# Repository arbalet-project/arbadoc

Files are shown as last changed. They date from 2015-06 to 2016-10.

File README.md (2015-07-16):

# Arbalet project
## Hackable LED table for geeks and pleasure
Arbalet is an *ARduino-BAsed LED Table*, a flat surface filled with several hundreds of coloured square lights designed for _Education_, _Geeks_, and _Pleasure_. With its limited number of pixels, Arbalet brings our old 80 arcad games back into fashion through a modern, classy, and hackable device.

Arbalet is intended to be easily reproducible, highly customizable, and programmable to create new games, light animations and applications. It's not only a LED table, it's an open development platform. Whether you're looking for a modern, stylish and ready-to-use platform for your home, or a hackable and original platform to teach programming and develop exciting projects, Arbalet is made for you!

Wanna get more information and/or start hacking? Please consult the [Arbalet wiki](https://github.com/arbalet-project/arbadoc/wiki), here is a video trailer to whet your appetite:

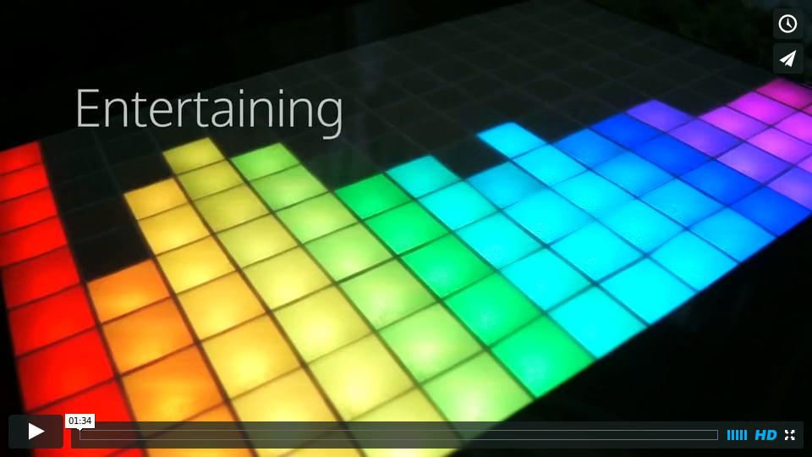
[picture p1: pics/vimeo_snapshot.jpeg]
Arbalet video trailer (https://vimeo.com/arbalet/1)


The project has just started and is looking for beta-testers and passionate makers, to keep in touch: Follow @arbalet_project on Twitter (https://twitter.com/arbalet_project)

## Arbadoc
Arbalet's source code is organized around three repositories: [Arbasdk](https://github.com/arbalet-project/arbasdk) (Python SDK), [Arbapps](https://github.com/arbalet-project/arbapps) (Applications) and Arbadoc.

This repository Arbadoc contains all extra files and pictures related to the documentation. This is probably not very interesting to browse this repository by hand, consult the [Arbalet wiki](https://github.com/arbalet-project/arbadoc/wiki) instead.

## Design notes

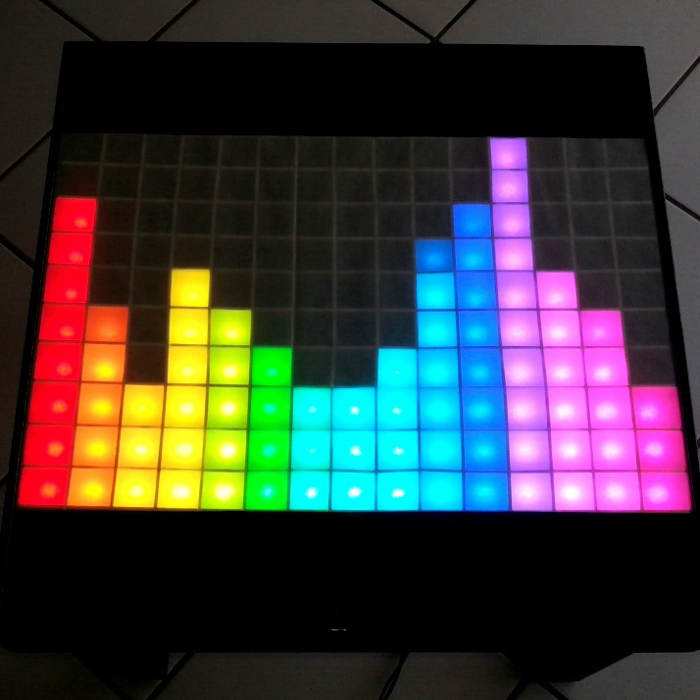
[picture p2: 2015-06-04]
pics/spectrum_analyser.jpg

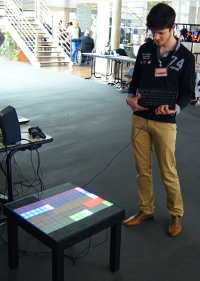
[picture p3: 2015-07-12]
pics/lights_hero_florian_thumbnail.jpg

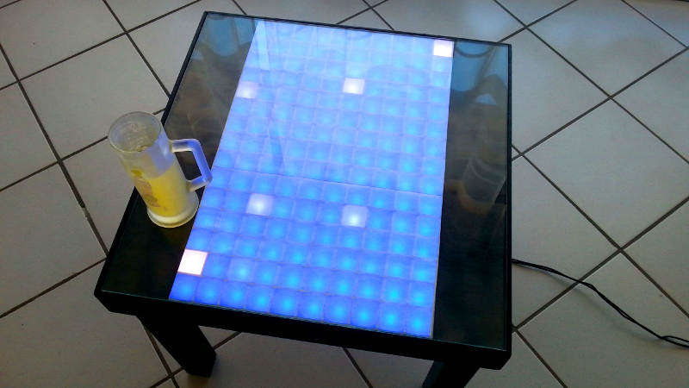
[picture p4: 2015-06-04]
pics/beer_and_flashes.jpg

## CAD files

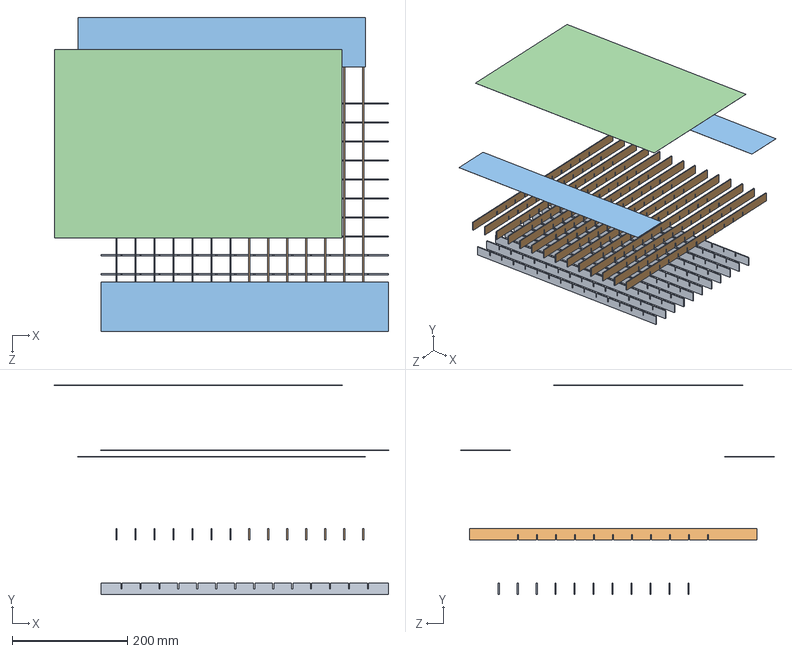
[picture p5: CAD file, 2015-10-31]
assembly_guidelines/lack/cad/Arbalet_GRID_ASM.SLDASM
580.8 x 363.9 x 545.8 mm
Arbalet_GRID_14 x 11
Arbalet_GRID_11 x 14
Arbalet_GRID_COVER x 2
Arbalet_GRID_Diffuser

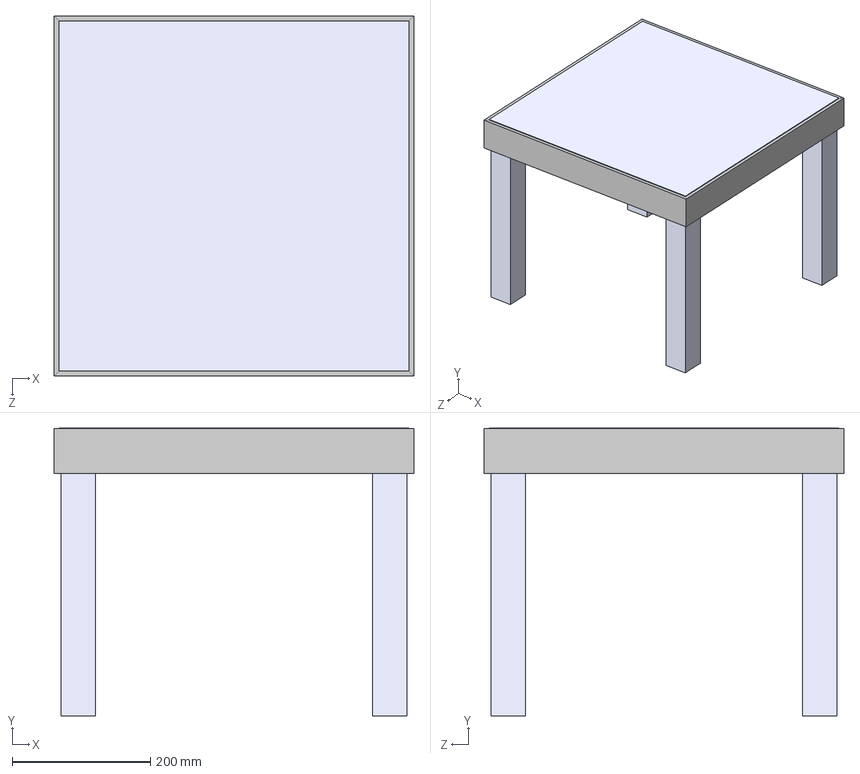
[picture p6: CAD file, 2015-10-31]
assembly_guidelines/lack/cad/Arbalet_ASM.STEP
520.0 x 416.0 x 520.0 mm
Arbalet_UPPER_TRAY_Glass
Arbalet_UPPER_TRAY_Frame x 4
Arbalet_GRID_14 x 11
Arbalet_GRID_11 x 14
Arbalet_GRID_COVER x 2
Arbalet_GRID_Diffuser
Arbalet_ELECTRONIC_STRIP x 10
Arbalet_TABLE_Tray
Arbalet_TABLE_LEG x 4
Arbalet_ELECTRONIC_Tape x 10

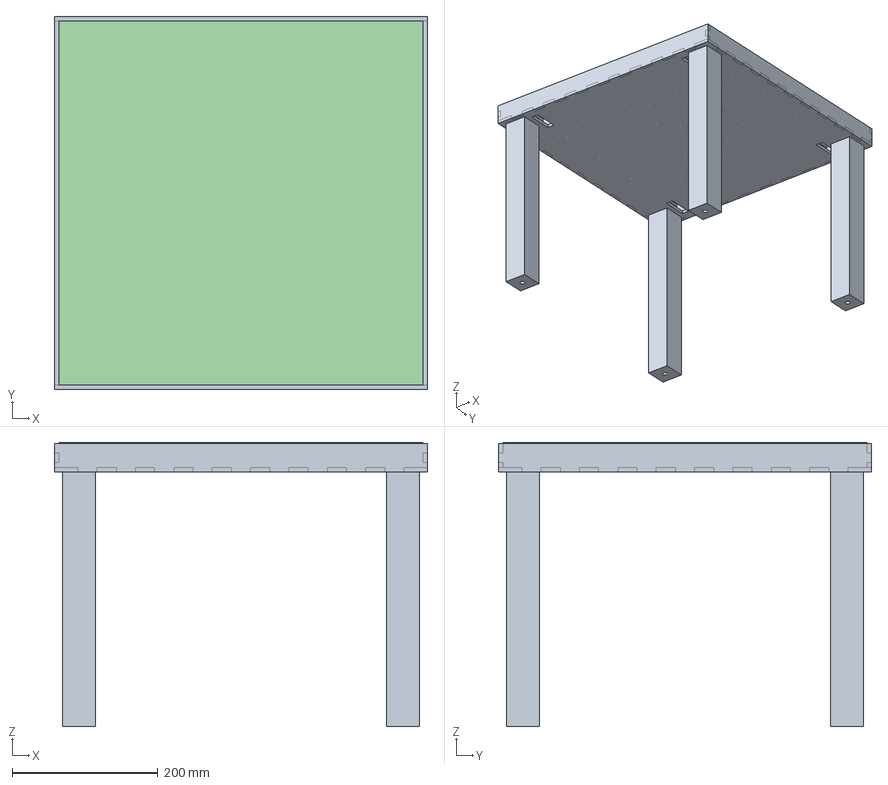
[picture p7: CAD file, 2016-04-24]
assembly_guidelines/lava/cad/covered_assembly.fcstd
512.0 x 512.0 x 390.5 mm
host_box_grid_legs_01
cover_sheet_01
cover_sheet_02
glass_01

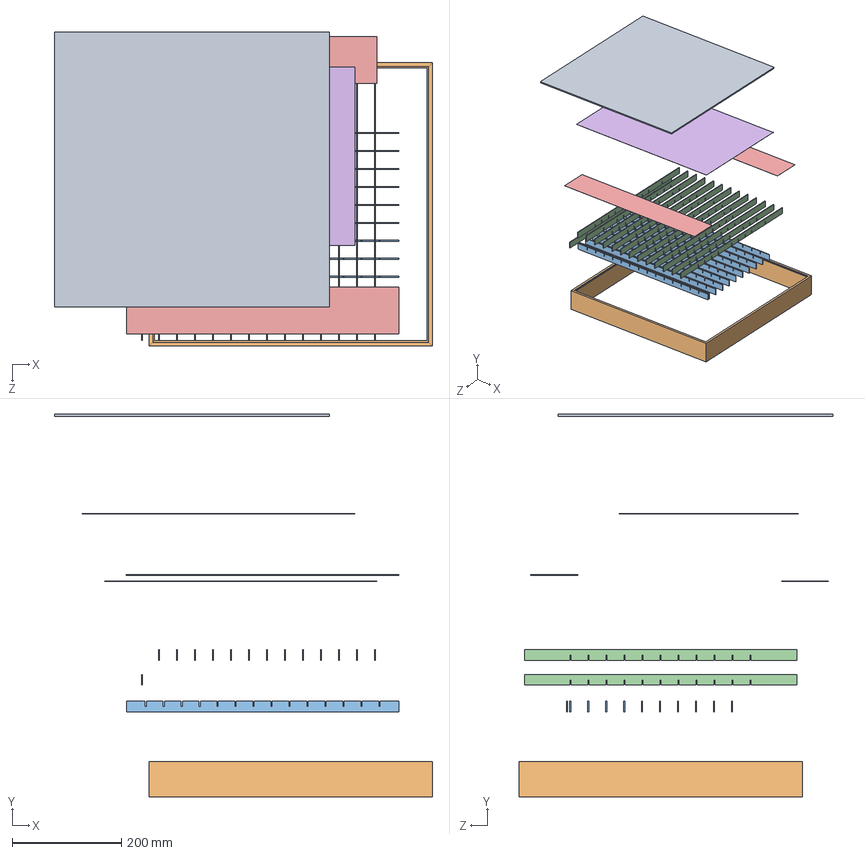
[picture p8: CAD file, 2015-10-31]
assembly_guidelines/lack/cad/Arbalet_UPPER_TRAY_ASM.SLDASM
693.6 x 702.2 x 576.6 mm
Arbalet_UPPER_TRAY_Glass
Arbalet_UPPER_TRAY_Frame x 4
Arbalet_GRID_14 x 11
Arbalet_GRID_11 x 14
Arbalet_GRID_COVER x 2
Arbalet_GRID_Diffuser

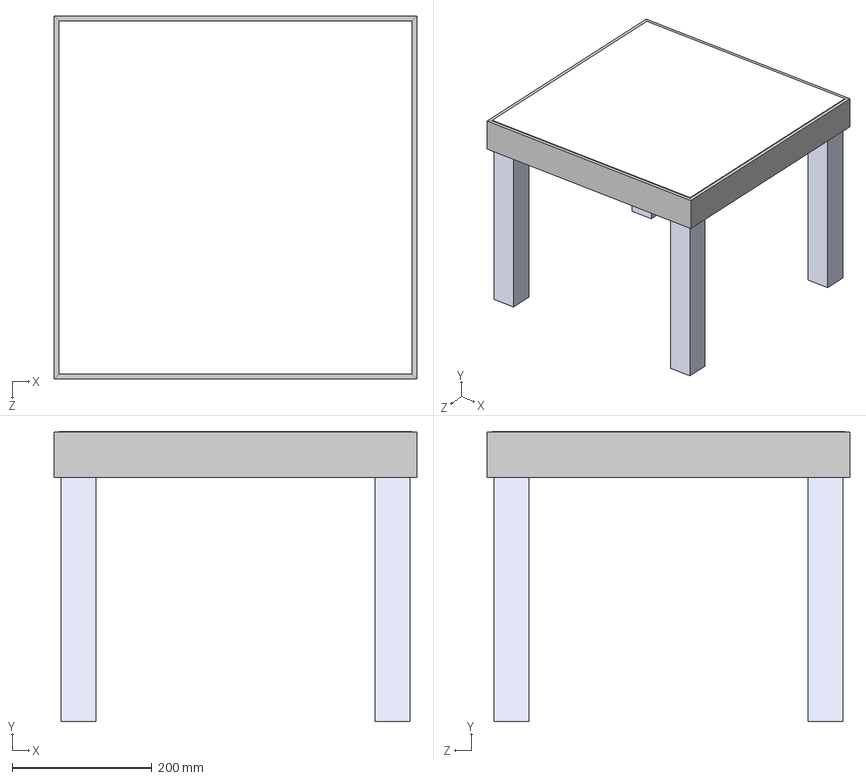
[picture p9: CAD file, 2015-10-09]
assembly_guidelines/lack/cad/Arbalet_ASM_step.STEP
520.0 x 416.0 x 520.0 mm
Arbalet_UPPER_TRAY_Glass
Arbalet_UPPER_TRAY_Frame x 4
Arbalet_GRID_14 x 11
Arbalet_GRID_11 x 14
Arbalet_GRID_COVER x 2
Arbalet_GRID_Diffuser
Arbalet_ELECTRONIC_STRIP x 10
Arbalet_TABLE_Tray
Arbalet_TABLE_LEG x 4

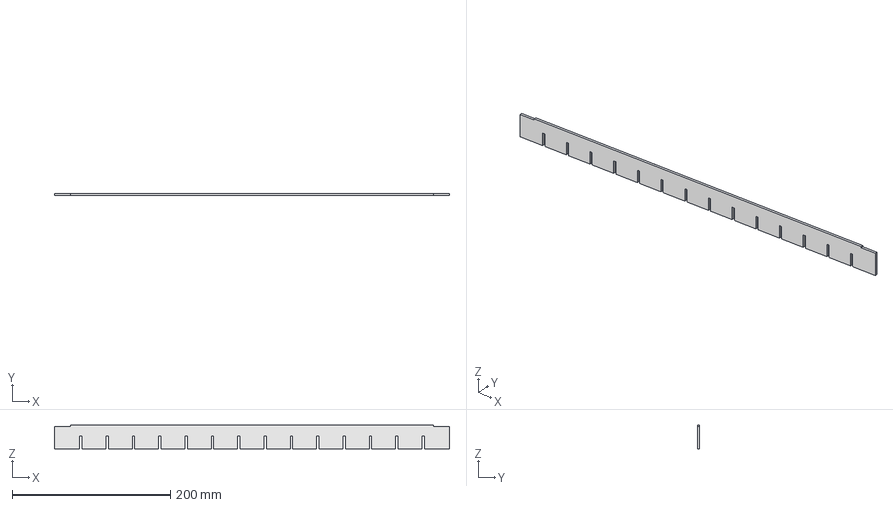
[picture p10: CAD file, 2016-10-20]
assembly_guidelines/lava/cad/strip_500_double.fcstd
500.0 x 3.00 x 30.0 mm

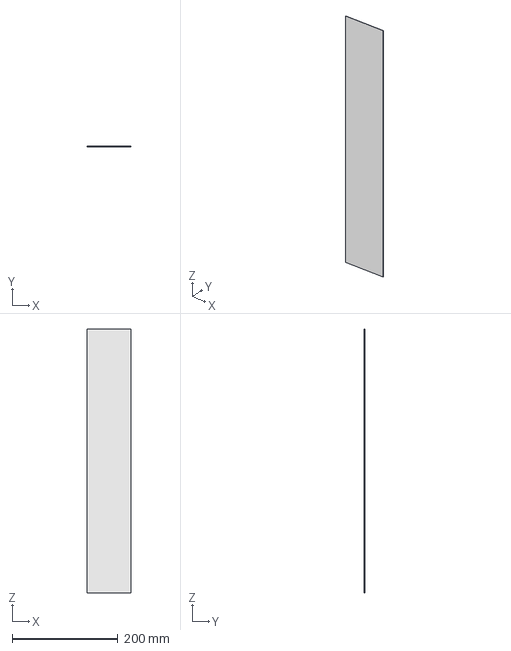
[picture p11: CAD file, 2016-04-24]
assembly_guidelines/lava/cad/cover_sheet.fcstd
83.3 x 0.5 x 500.0 mm

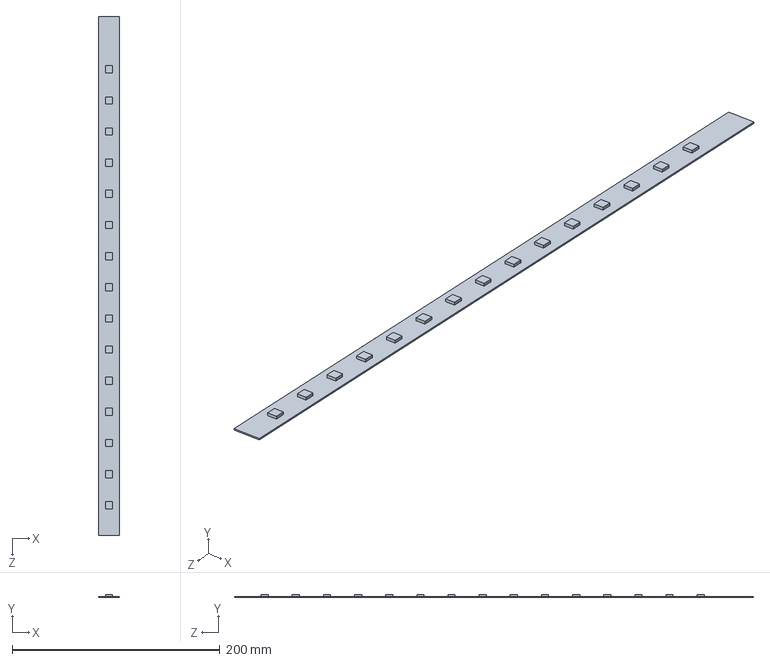
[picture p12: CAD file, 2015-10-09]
assembly_guidelines/lack/cad/Arbalet_ELECTRONIC_Strip.SLDPRT
20.0 x 3.00 x 500.0 mm

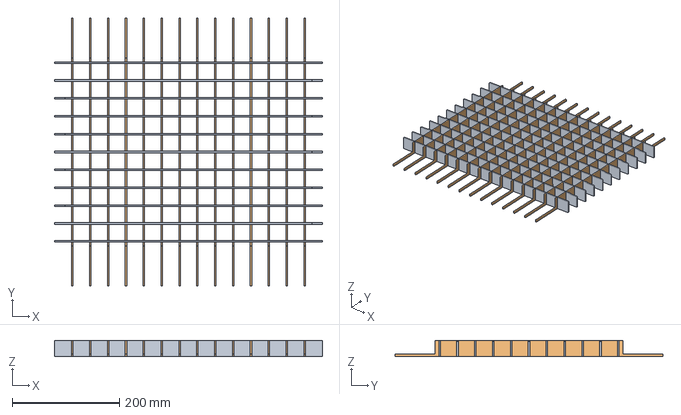
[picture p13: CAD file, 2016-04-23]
assembly_guidelines/lava/cad/grid.fcstd
500.0 x 500.0 x 30.0 mm
strips_500_01
strips_333_01

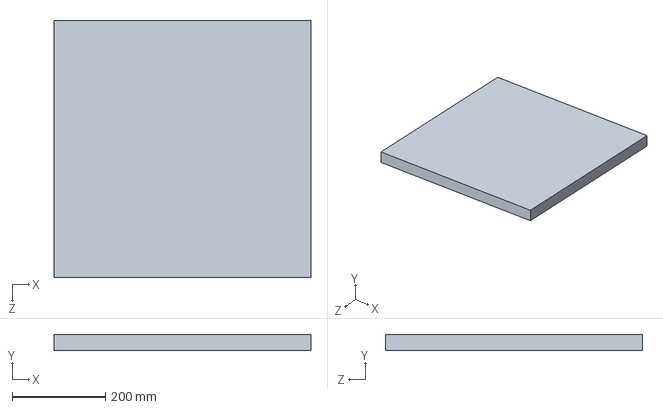
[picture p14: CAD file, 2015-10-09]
assembly_guidelines/lack/cad/Arbalet_TABLE_Tray.SLDPRT
550.0 x 35.0 x 550.0 mm

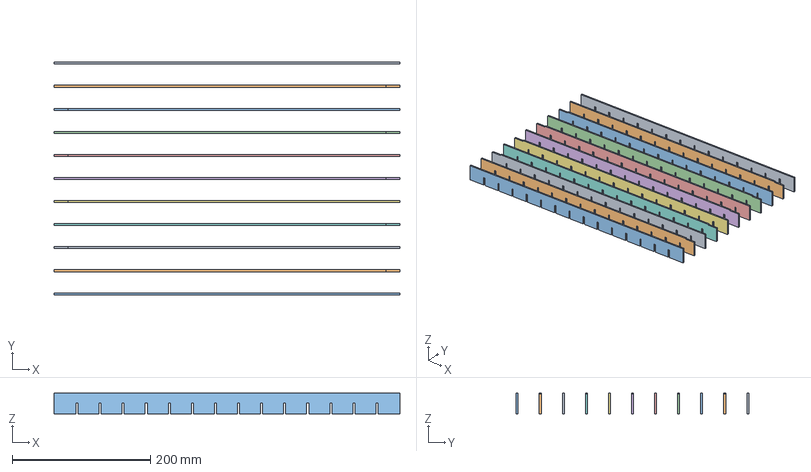
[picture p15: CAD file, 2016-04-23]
assembly_guidelines/lava/cad/strips_500.fcstd
500.0 x 336.3 x 30.0 mm
strip_500_01
strip_500_02
strip_500_03
strip_500_04
strip_500_05
strip_500_06
strip_500_07
strip_500_08
strip_500_09
strip_500_10
strip_500_11

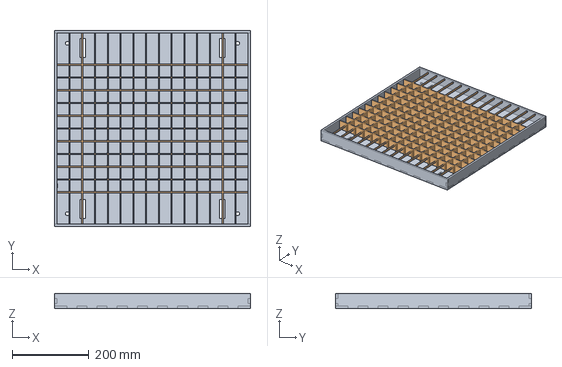
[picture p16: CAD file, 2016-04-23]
assembly_guidelines/lava/cad/host_box_grid.fcstd
512.0 x 512.0 x 39.0 mm
host_box_01
grid_01

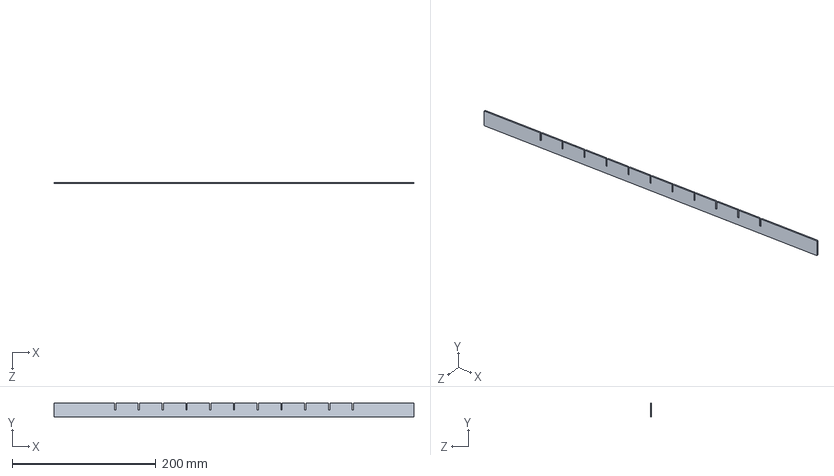
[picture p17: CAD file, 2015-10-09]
assembly_guidelines/lack/cad/Arbalet_GRID_11.SLDPRT
500.0 x 20.0 x 2.00 mm

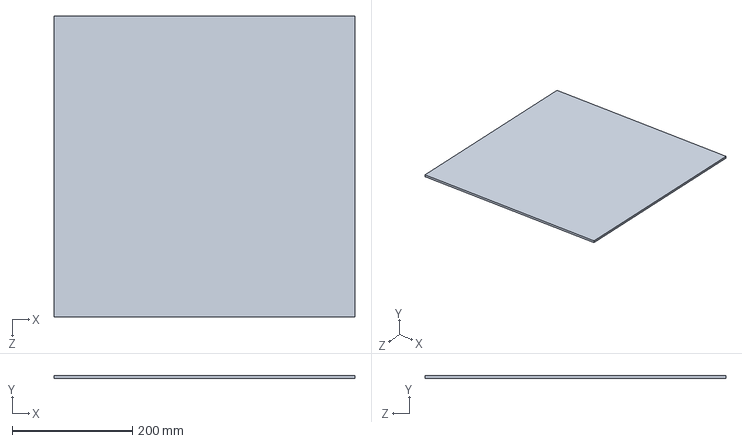
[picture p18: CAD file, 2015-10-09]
assembly_guidelines/lack/cad/Arbalet_UPPER_TRAY_Glass.SLDPRT
500.0 x 5.00 x 500.0 mm

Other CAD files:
assembly_guidelines/lack/cad/Arbalet_TABLE_ASM.SLDASM
assembly_guidelines/lava/cad/strip_500_extremity.fcstd
assembly_guidelines/lava/cad/host_box_grid_legs.fcstd
assembly_guidelines/lava/cad/leg.fcstd
assembly_guidelines/lack/cad/Arbalet_ASM.SLDASM
assembly_guidelines/lack/cad/Arbalet_ELECTRONIC_Tape.SLDPRT
assembly_guidelines/lack/cad/Arbalet_GRID_14.SLDPRT
assembly_guidelines/lack/cad/Arbalet_GRID_Cover.SLDPRT
assembly_guidelines/lack/cad/Arbalet_GRID_Diffuser.SLDPRT
assembly_guidelines/lack/cad/Arbalet_TABLE_Leg.SLDPRT
assembly_guidelines/lack/cad/Arbalet_UPPER_TRAY_Frame.SLDPRT
assembly_guidelines/lack/cad/MEP/Arbalet_ASS.SLDDRW
assembly_guidelines/lack/cad/MEP/Arbalet_ASS_eclatee.SLDDRW
assembly_guidelines/lava/cad/bottom.fcstd
assembly_guidelines/lava/cad/glass.fcstd
assembly_guidelines/lava/cad/host_box.fcstd
assembly_guidelines/lava/cad/side_333.fcstd
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

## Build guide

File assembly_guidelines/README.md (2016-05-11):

# Arbalet assembly guidelines

You will find here the assembly guidelines of all Arbalet variants. That will grow up as the community develop new derived LED surfaces.

## Arbalet Lack (v1)

This variant is made to reuse and hack a 500x500mm Ikea coffee table "Ikea Lack" with no particular machine except traditional tools (saw, screws).

## Arbalet Lava (v2)
This variant is made to be easily reproducible in fablabs from scratch, i.e. with no initial furniture. It relies on laser cutting machines whose most fablabs are equipped with.
CAD files and 2D patterns are provided for a precise cut are provided. It also comes with a 6-key touch interface.

## Variant merging
A manually cut grid (Lack) might be a bit twisty due to the lack of precision with traditional tools while a laser cut grid ends up in perfect square pixels.

Therefore, in practice you might want to merge both variant to make your own, e.g. you can hack your existing Ikea table and reuse 2D patterns of the grid to make it precise, or also to make it touch-compatible.
Let us know if you create new CAD or assembly plans for your furniture!

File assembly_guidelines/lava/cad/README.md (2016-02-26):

# Arbalet LAVA CAD files
## Requires FreeCAD 0.16
This variant is modeled thanks to [FreeCAD software](http://freecadweb.org/). As of February, 2016, the last stable version is FreeCAD 0.15.
However, these files use a new "expressions" feature available from 0.16. This feature allow to parameter datums and vary the thickness of materials. See http://www.freecadweb.org/wiki/index.php?title=Expressions 

To install the last development version on Ubuntu: 
http://freecadweb.org/wiki/?title=Download#Ubuntu_PPA_packages

## Assemblies require the Assembly 2 plug-in

Please install the [Assembly 2 plugin](https://github.com/hamish2014/FreeCAD_assembly2#freecad_assembly2) to be able to load assemblies and constraints.
It is not necessary to regenerate parts individually unless you need pictures of assemblies, but its overlap checking feature are very useful to check for defects.

## How to change parameters:

By changing any of these parameters FreeCAD will compute the other parameters.

Parameters:

* Thickness of the external wood: bottom#Slab.Height
* Thickness of the wood of the grid: strip_500#Strip.Width
* Thickness of the glass: glass#Glass.Height (Do not neglect, the rim of its host is based on that)

However, parts are not individually updated when a parameter changes in another file, execute the [ForceRecompute macro](http://www.freecadweb.org/wiki/index.php?title=Macro_ForceRecompute) in cascade for individual parts and then click on the "Update parts imported into the assembly" buttons for the assemblies.

## Notes
As of Feb, 2016, intervals of arrays have no units, thus in `(1000mm/3 + Slab.Height)/1mm` the last `/1mm` is only used to simplify the units of the result.

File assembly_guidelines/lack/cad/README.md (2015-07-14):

# CAD files for Arbalet Lack

This folder contains CAD files for Arbalet Lack variant. It's a hack of the standard Ikea Lack coffee table.

We are sorry these files require a closed-source proprietary CAD software Solidworks by Dassault Systèmes. If you have the competences to port this work on [FreeCAD](http://freecadweb.org/), you are very welcome to join us, fork the repository and open a pull request.

Note that students are given a free copy of Solidworks [upon request](http://www.solidworks.com/sw/education/SDL_form.html).

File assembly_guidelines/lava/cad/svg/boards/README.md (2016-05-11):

# Boards for Arbalet Lava (v2) <English>

This folder contains the files of laser cutting to build Arbalet Lava. They allow to build a table whose internal grid is 3mm thick and its outer host box 5mm **OR** 6mm.

It is advised to use MDF wooden boards (aka medium) very stable and resulting in a clean laser cut to make the construction easier.

The 150 tiny holes in the host box (5 or 6mm) are made to pass wires for future touch detection via capacitive sensors, the 4 rectangles are hatches for microcontrollers.
The bottom-right side of 12 vertical strips (over 14) is also slighly cut to pass wires of the LED strip.

The detailed assembly guidelines of Arbalet Lava can be found [online](https://github.com/arbalet-project/arbadoc/blob/master/assembly_guidelines/lava/assembly_guidelines_arbalet_lava.pdf).

# Planches pour Arbalet Lava (v2) <French>
Ce dossier contient les fichiers de découpe laser pour construire Arbalet Lava. Ils permettent de construire une table dont la grille intérieure a une épaisseur de 3mm et la boîte hôte extérieure 5mm **ou bien** 6mm.

Il est conseillé d'utiliser des planches de bois MDF (aussi appellées medium) très stables et donnant une découpe propre pour faciliter la construction.

Les 150 petits trous dans la boîte hôte (5 ou 6mm) sont fait pour passer les fils en prévision d'une détection tactile via des capteurs capacitifs, les 4 rectangles sont des trappes techniques pour les microcontroleurs.
En bas à gauche de 12 bandes verticales (sur 14 en tout) se trouvent également des trous pour passer les câbles de la bande de LED.

Le guide d'assemblage détaillé d'Arbalet Lava peut être consulté [en ligne](https://github.com/arbalet-project/arbadoc/blob/master/assembly_guidelines/lava/assembly_guidelines_arbalet_lava.pdf).

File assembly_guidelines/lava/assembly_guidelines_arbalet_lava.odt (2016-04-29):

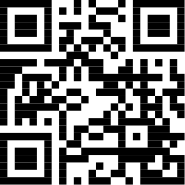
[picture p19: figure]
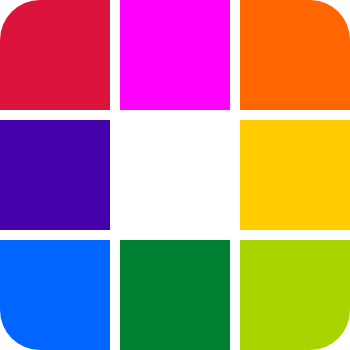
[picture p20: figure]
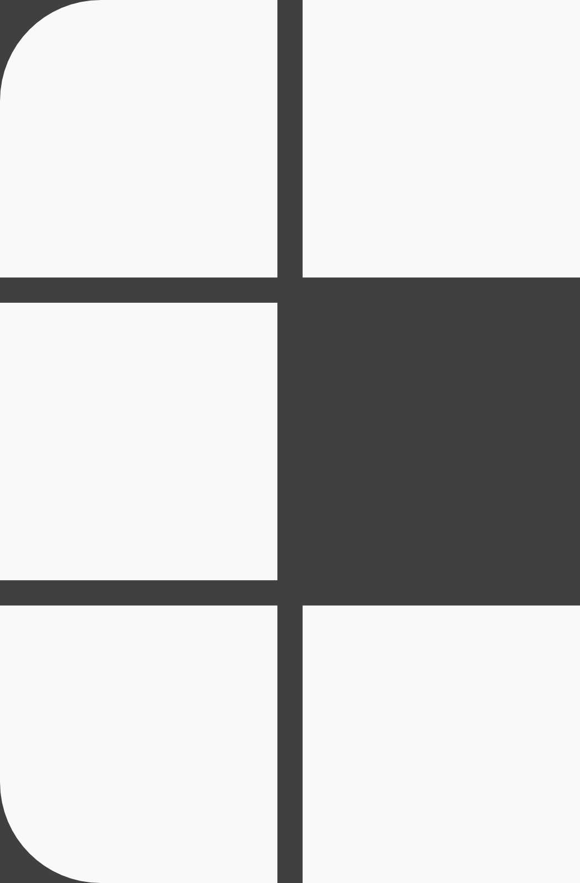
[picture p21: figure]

Arbalet LED table

Lava variant

Assembly guidelines for DIY building

Beta version, last edit: 29 April 2016

Preliminary notes

This document describes how to build an Arbalet LED table licensed under an Open Hardware CC-BY-SA licence (https://creativecommons.org/licenses/by-sa/3.0/). It is then permitted and formally encouraged to take inspiration from this work to build new Open Hardware items and publish them to the community.

Lava is the Laser-cut variant, designed to be easily reproducible with standard equipment of fablabs.

# Bill of Material (BOM)

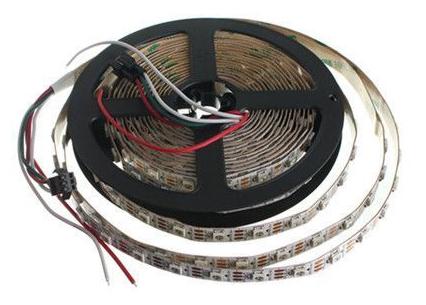
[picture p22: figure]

## 5 meters of WS2812B strip

It is possible to use non-WS2812B LEDs, however this might require software changes. Unless you know what you do, choose a strip that matches these requirements:

- 150 LEDs

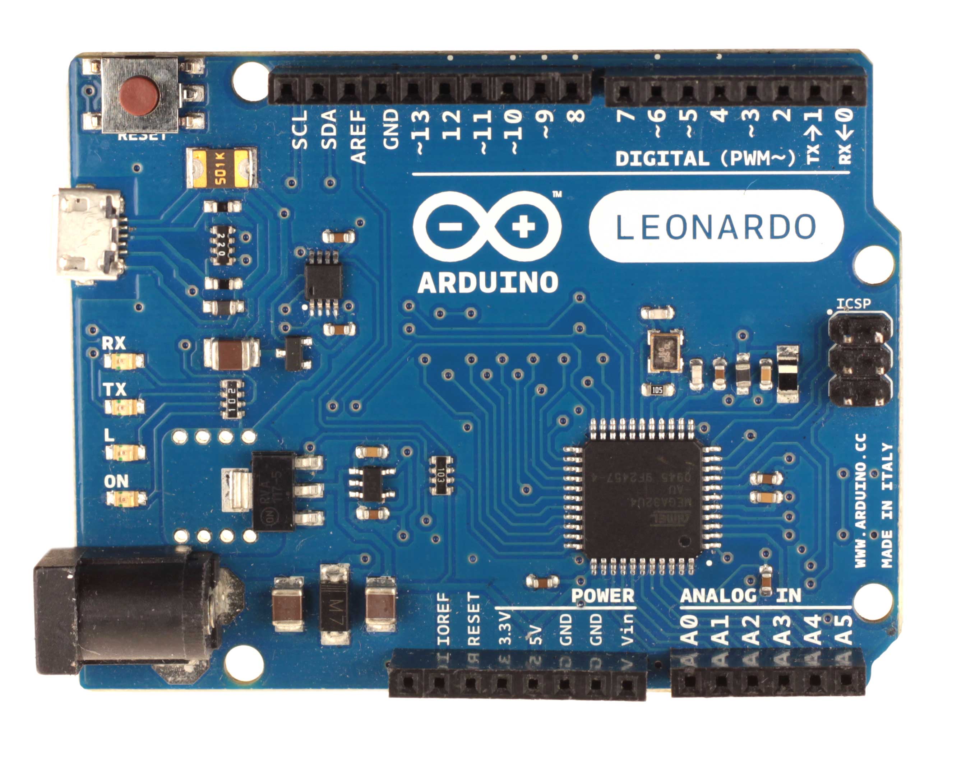
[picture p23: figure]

- Density 30 LED/meter (33.3mm between each LED)

## Arduino Leonardo microcontroller

Other Arduino board are also usable, however Uno's serial connection is not much stable. Do not forget its USB cable.

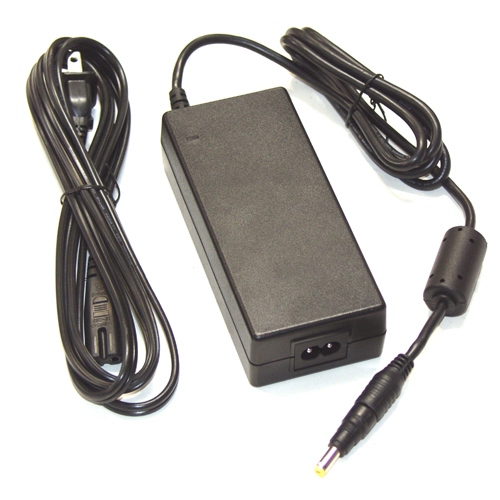
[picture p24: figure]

## A 5V AC → DC wall adapter >5A

Use a regulated power supply of at least 5 amps.

## A bunch of electrical wires

The wires will be used to connect the cut sections of the LED strip. We will need to connect 3 wires: Power + (red), Power - (black) and Data (green, or any other color).

The 2 power wires will drive up to 5A and might melt if they are too thin. The strip is sold with a 20 AWG cable, meaning that its copper inner wire is 0.8 mm thick. You should keep this section for the 2 power wires for safety purposes. For the Data line, you might use a very thin wire as it drives very few current. If you want to calculate precisely the section of power wires, refer to the standard (https://en.wikipedia.org/wiki/American_wire_gauge).

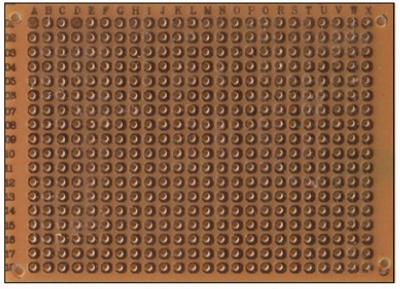
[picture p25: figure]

## A credit card sized soldering board

This card will go right above the Arduino, fastened to the microcontroller thanks to pin headers. You can also use soldering boards dedicated to Arduino, already mounted with PIN headers and screw connectors if you're not familiar with soldering.

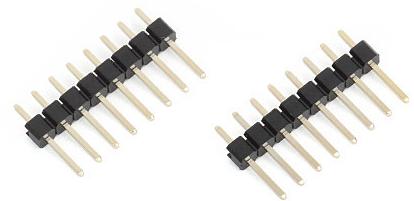
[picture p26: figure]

## Some male pin header

## A 100 to 200 µF capacitor (optional)

If your power supply is shoddy, this capacitor can help it to provide enough energy to the LED strip in case of peaks of current, for instance when all pixels are suddenly lit from black to full brightness.

## 600x600mm of 5 or 6 mm-thick MDF wood (medium)

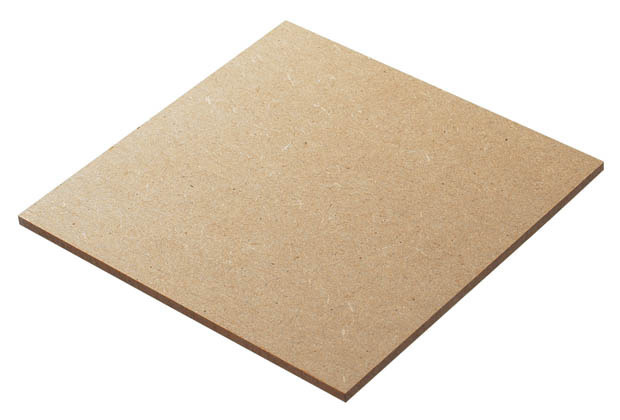
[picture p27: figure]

This thick board will be used to build the external host box of the table. Online plans are made for both 5mm or 6mm thicknesses.

Make sure you can cut these boards precisely thanks to a laser-cutting machine (most fablabs have one) and that it's actually able to handle pieces of wood of that size from SVG files.

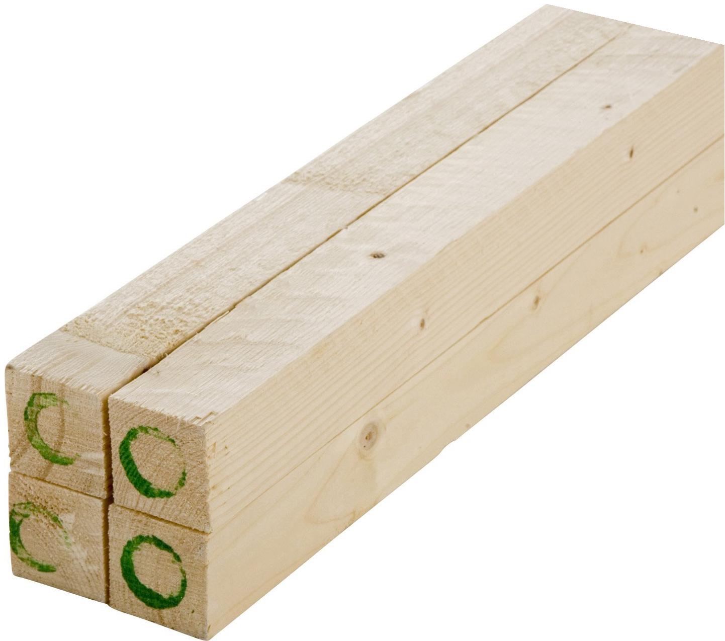
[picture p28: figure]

## 800x600mm of 3mm-thick MDF wood (medium)

This thin board will be used to build the internal grid delimitating pixels.

## 4 battens of 50x50mm, 400mm-long

These battens will be used are table legs.

## 4 Double-threaded bolts, washers and butterfly nuts

These will allow to assembly the legs. One side of each bolt must be screwed into the battens here above, the nuts will be screwed on the other side. The first side must be suitable to screw into wood. Choose the biggest diameter possible up to 10mm. High diameter will allow more stability.

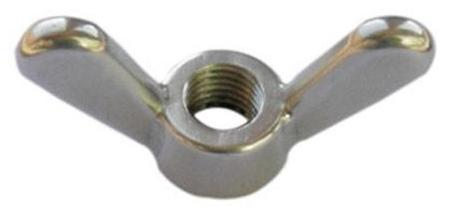
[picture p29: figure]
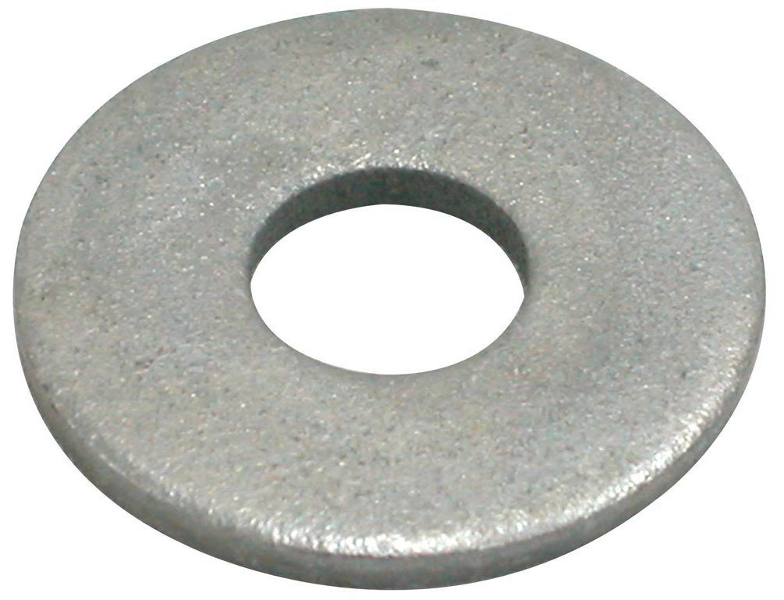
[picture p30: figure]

## 498x498mm of 4mm-thick glass or plexiglass

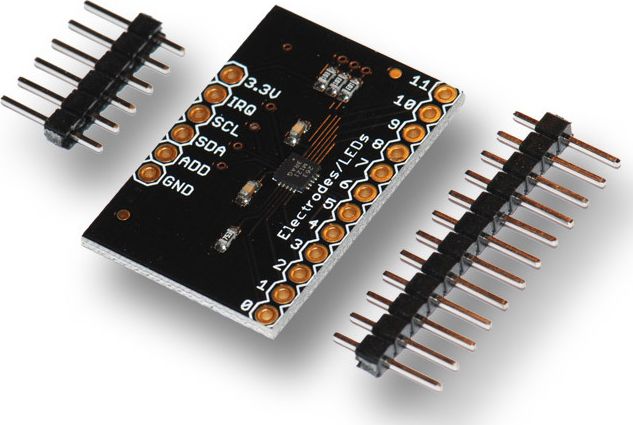
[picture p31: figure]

This will be the upper tray of the table. This glass will support your bottles, glasses and remote controls after building ;-)

## A MPR 121 sensor with I2C (optional, for touch)

This cheap capacitive sensor will provide 12 touch keys to your Arbalet.

## ITO (Indium Tin Oxide) plastic (optional, for touch)

ITO is a conductive liquid. When painted on a flexible plastic sheet it allows to make it conductive by keeping its transparency. A piece of ~200x100 mm of ITO transparent plastic will make you able to create several touch keys for your Arbalet.

# Preliminary advices

You definitely not have to be expert in computer science or electronics expert to build your Arbalet table. Everything is made to simplify as much as possible the setup. You are then free to bring your own touch by customizing it through new software development, better aesthetic furniture integration or new features. You might want to get in touch with a fablab (fabrication laboratory) (https://www.fablabs.io/map) where people will be happy to help you.

Before mounting your table, check out the timelapse of assembly (https://vimeo.com/arbalet/2) that will give you a good overview of the different assembly steps. The overall assembly presented in the video lasts only 2 hours but it assumes that all spare parts are ready and the wooden boards cut.

# Laser cutting

Pick your medium density fiber boards (MDF) and go to the closest fablab. A fablab manager there will help you using a laser-cutting machine to cut the pieces of wood.

SVG files are online for 3, and 5 or 6mm boards. You need only one thickness among 5 and 6, depending of the material you find more easily in your local retail store.

Download the SVG files (https://github.com/arbalet-project/arbadoc/tree/master/assembly_guidelines/lava/cad/svg/boards) and make sure the software is able to load them properly before cutting. The 150 tiny holes in the host box (5 or 6mm) are made to pass wires for future touch detection via capacitive sensors, the 4 rectangles are hatches for microcontrollers. The bottom-right side of 12 vertical strips (over 14) is also slightly cut to pass wires of the LED strip.

If necessary you might regenerate the SVGs from CAD (https://github.com/arbalet-project/arbadoc/tree/master/assembly_guidelines/lava/cad) files using FreeCAD.

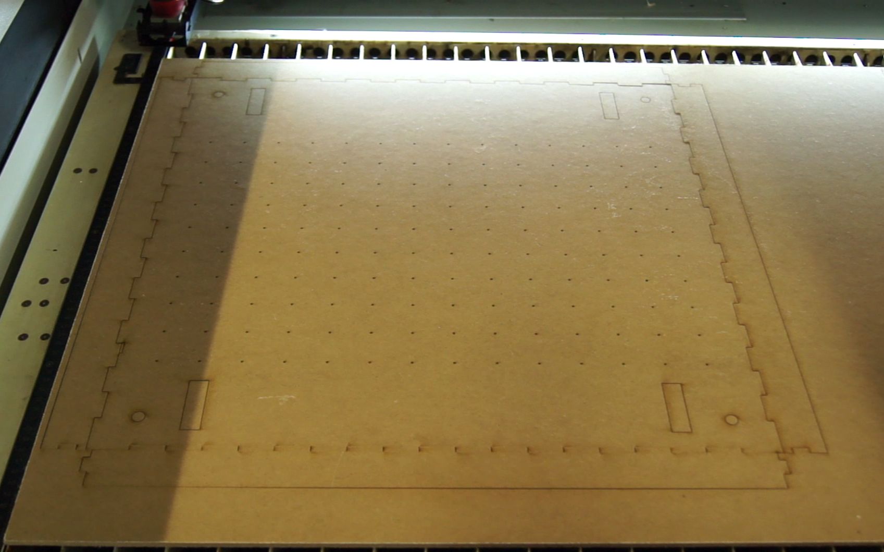
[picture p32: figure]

After cutting you might consider painting one side of the 5mm/6mm parts using a spray-paint can or a brush, that will be the outer side. The other side (inner) can be painted in white for a better light reflection.

Touch wires passings (x150, ⌀ 1.5mm)

Leg holes (x4, ⌀ 10mm)

Cable passings/Technical hatches (x4)

# Legs preparation and assembly

According to the diameter of your bolts, pre-pierce the battens by choosing the drill bit right smaller than the bolt diameter ; e.g. 7mm for a bot of 8mm.

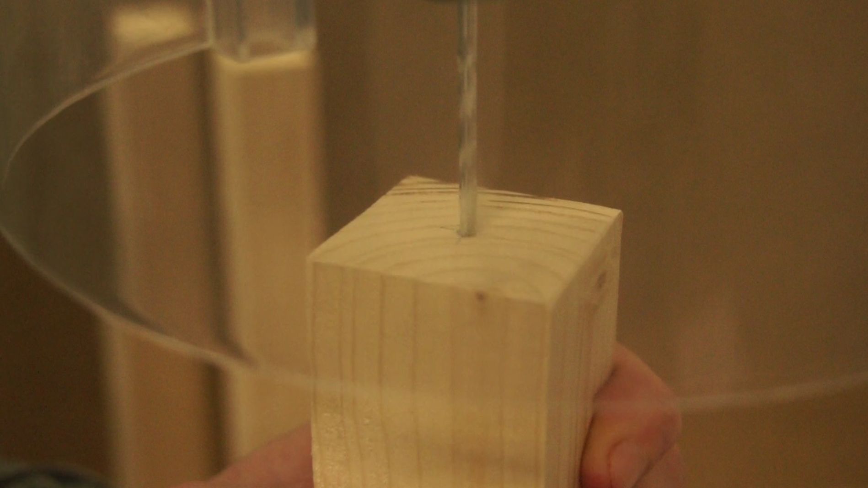
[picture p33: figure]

Then screw the 4 bolts into the 4 legs. You can use the nuts to force.

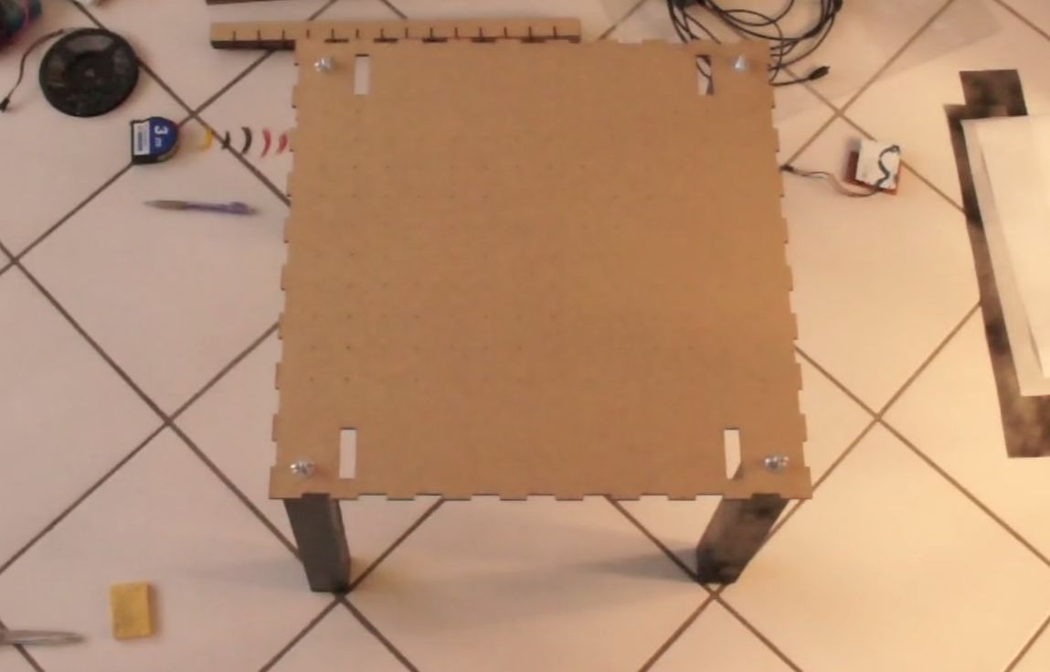
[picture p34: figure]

Finally, assemble the 4 legs to the main part of the host box using washers and nuts.

# LED strip cutting

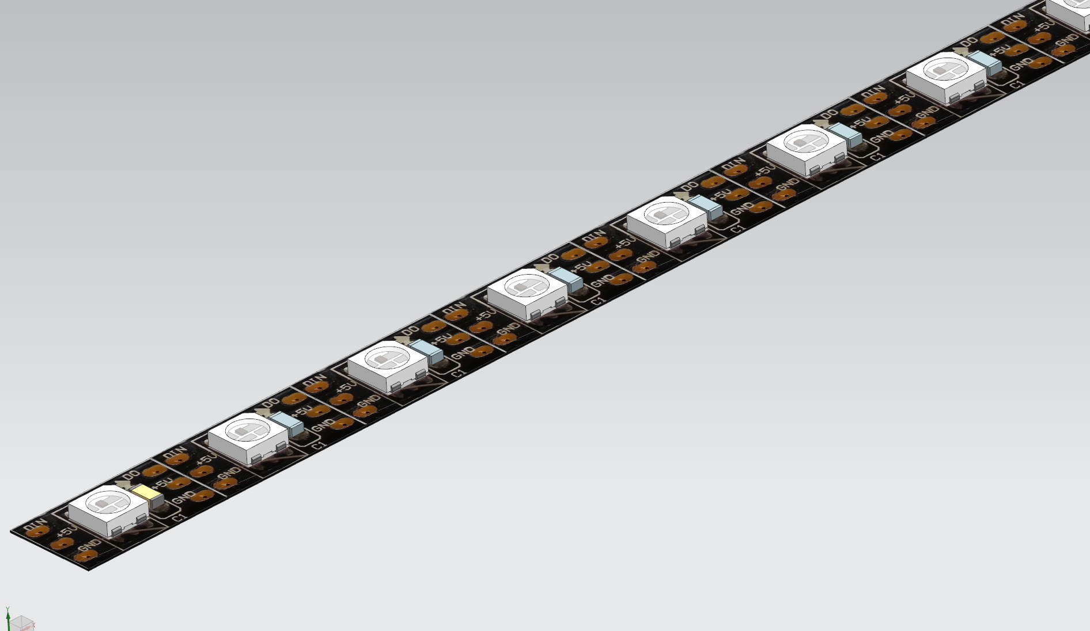
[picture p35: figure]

Unroll the LED strip, observe the arrows noticing the data signal. These LEDs are soldered on a serial bus: each DOUT pin (aka DO, for data out) is connected to a DIN (data IN). Thus the strip has an input and an output.

Data signal You LED strip comes with connectors factory-soldered 3-pin JST SM at both ends. The male connector is soldered to the input, the female to the output. Unsolder the output (female) connector but keep the input one.

Using scissors cut the strip every 500mm = 15 LEDs. Make sure you cut in the middle of a coppered connection. This area is often marked by a sign

You must end up with 10 strips of 15 LEDs, whose one has a male connector.

# LED strips gluing

Using a pencil, trace the lines where you will glue the pieces of strips. They are 10 lines horizontally centred. The host box is not symmetric, make sure you trace them in the vertical direction (see picture).

The first column must be traced 83.3mm from the edge, then each line is 33.3mm from the previous one. The distance between the first and the last (10th) line is 333.3mm.

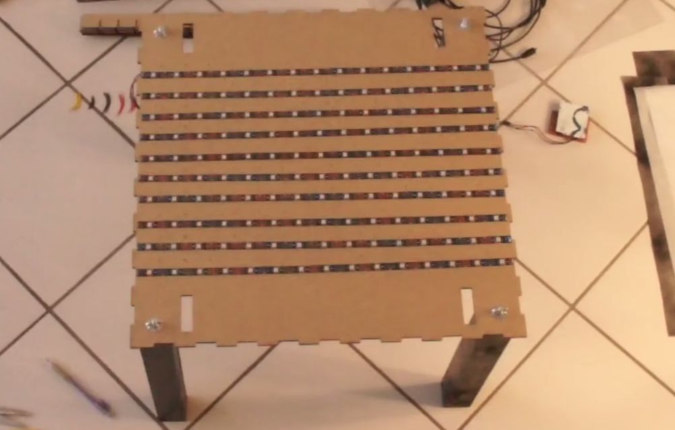
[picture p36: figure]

Horizontal direction Vertical directionThen pre-place the 10 pieces of strips according to next diagram. It is primordial that you alternate each piece of strip. For this you can rely on their arrows whose direction must change each column: → ← → ← and so on…

Rectangle cable-passing in the main tray

connector

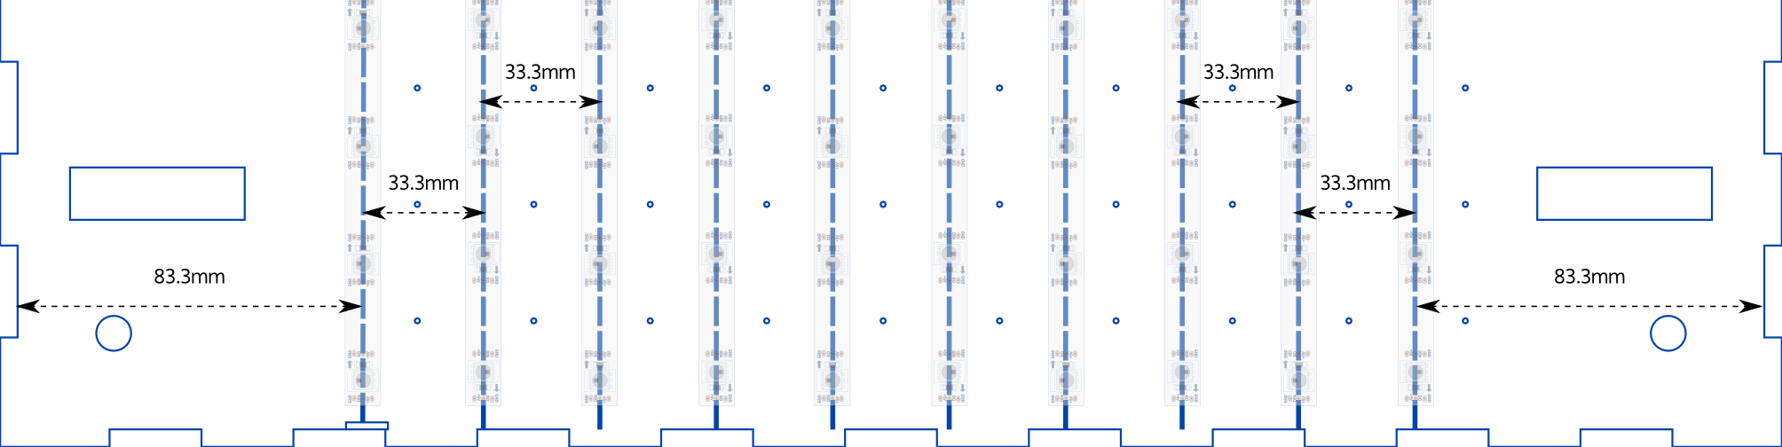
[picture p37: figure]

WARNING: Keep in mind that we will reconnect the electrical connection between cut strips, by forming a coil. The coil is a succession of DIN to DOUT connections. Double check that you're always connecting DOUT to the next DIN. Never connect ~~DIN to DIN~~ nor ~~DOUT to DOUT~~.

Glue the pieces of strips on your pencil lines once you are sure the Data line forms a coil.

Cut and strip 9x3 = 27 pieces of wires to reconnect the data and power lines between each piece of strip. Connect 5V (red) together, GND (black) together, and DATA (often green or yellow) together, as shown on the electrical diagram next page.

Also connect the power supply of both extremities (GND to GND and 5V to 5V) via 2 direct wires. It allows to better dispatch the power to avoid a difference of colour at extremities.

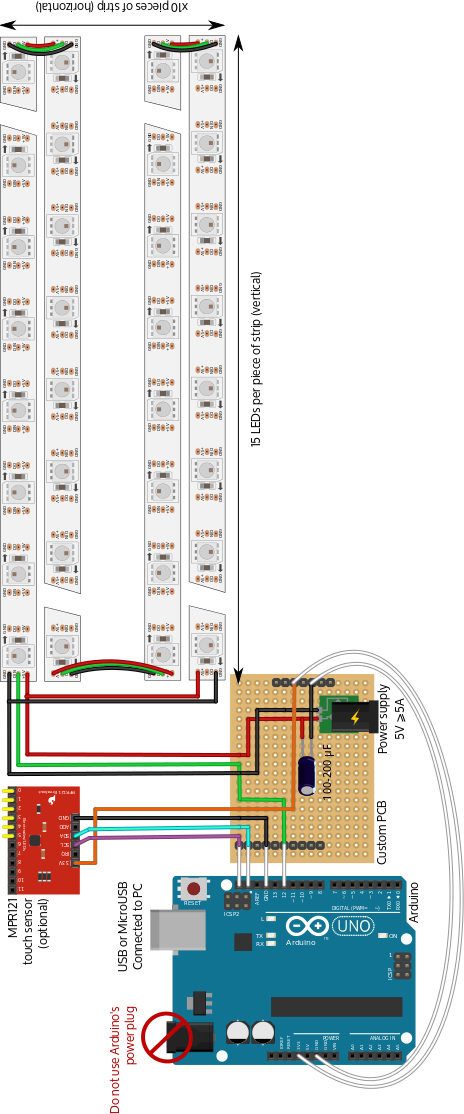
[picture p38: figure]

# Solder the circuit board

Arbalet's electronics, illustrated on the previous diagram, is composed by:

- An Arduino board (in blue), connected to a computer through USB
- A custom PCB (in brown), connected to a 5V power supply
- An optional touch sensor MPR121 (in red) connected to 6 active surfaces (yellow pins)

The custom board will be mounted right above the Arduino board, with its male PIN headers directly plugged in Arduino's female headers, ensuring its fastening as well as its data connection.

Solder the components and connections on the custom board as shown on the diagram previous page. White wires on the diagram are not actual wires but direct male-female connections of PIN headers.

Components will be wedged between both boards, so make sure that there are not too big to avoid the boards being plugged together. The capacitor and the DC power plug are the big components that could prevent connection of boards.

If you are planning to plug a touch sensor, we will detail this later on, however at this step you must make sure it will be easy to solder the 4 wires of the sensor (orange, black, cyan, purple).

Then follow the Hardware and Software preliminaries (https://github.com/arbalet-project/arbadoc/wiki/Hardware-and-Software-preliminaries) until Arbalet firmware is uploaded before continuing. If something went wrong during soldering you will figure it out during these tests before it becomes less easy to fix the hardware problems.

Place your electronics on the side and jump to step 8 only after having successfully run at least the colour demonstrator on your new hardware using the -w flag to enable hardware. Ensure that all pixels are driven and able to light. If you meet troubles, find help in the troubleshooting (https://github.com/arbalet-project/arbadoc/wiki/Troubleshooting) section.

# Assemble the inner grid

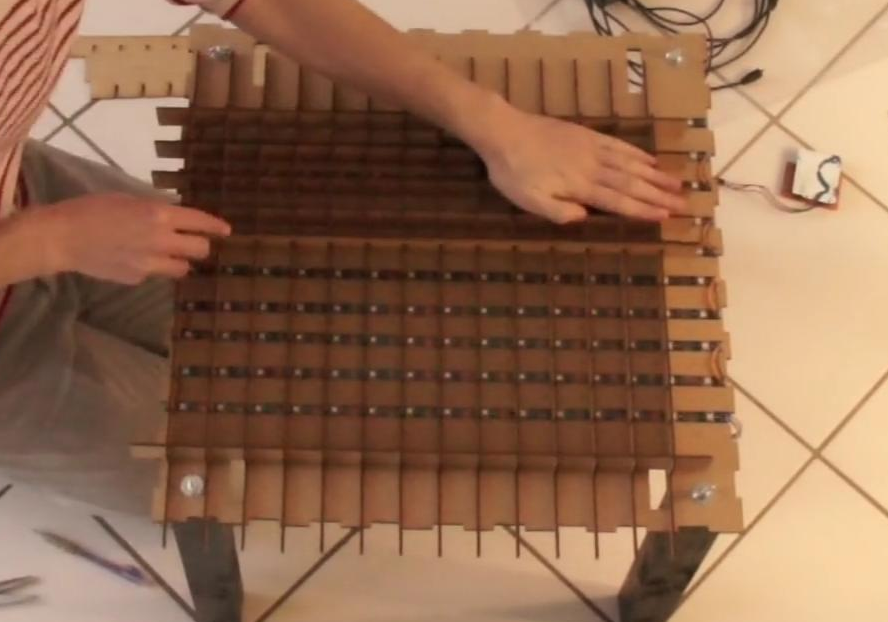
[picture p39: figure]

The 3mm medium board has been cut into 11 vertical and 14 horizontal strips. The horizontal ones have side rods creating two side cavities that will host electronics and support the upper tray.

Side rods

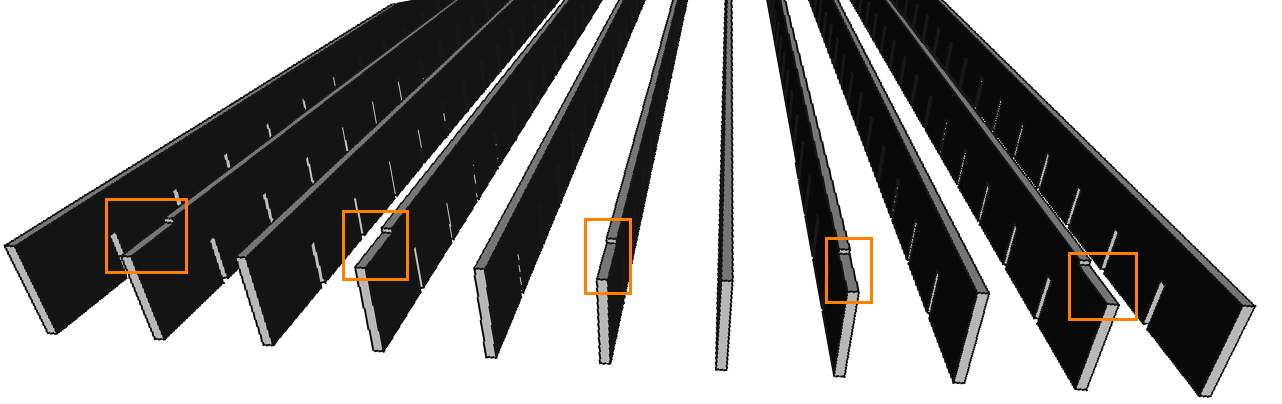
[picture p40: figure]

Notice that 9 vertical strips have wire passings. They are made for the data line you have soldered at step 6. Make sure you alternate them as shown on the drawing hereafter. Orange areas emphasis the alternation of wire passings on one side. The two strips with no wire passing go at the extremities.

Assemble the whole grid made of vertical and horizontal strips by sliding strips into each other as shown on the next drawing.

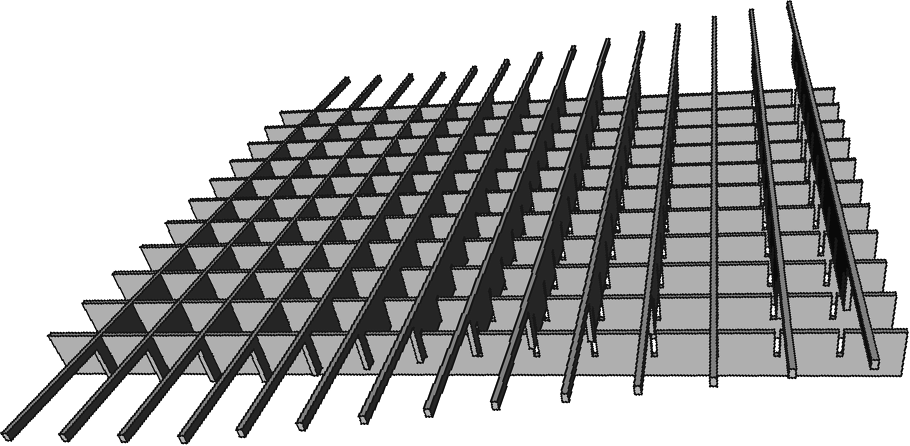
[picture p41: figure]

Then eventually rotate the final construction upside down so that side roads are at the top (only the last illustration respects this orientation). Finally move the grids on the table tray so that each pixel the structures has created matches a LED.

# Close the table

Position and glue the 4 laser-cut sides of the tray. Cut pieces of cooking paper covering the pixels area that will help diffuse the light, as well as two side covers to hide the side cavities hosting electronics.

Finally, cut a piece of glass or plexiglass of 498x498mm, keeping a degree of freedom of 2mm on each side to ensure an easy placing and removing of the glass. The online plans are more suited for 4mm-thick glasses but other thickness will be fine as well.

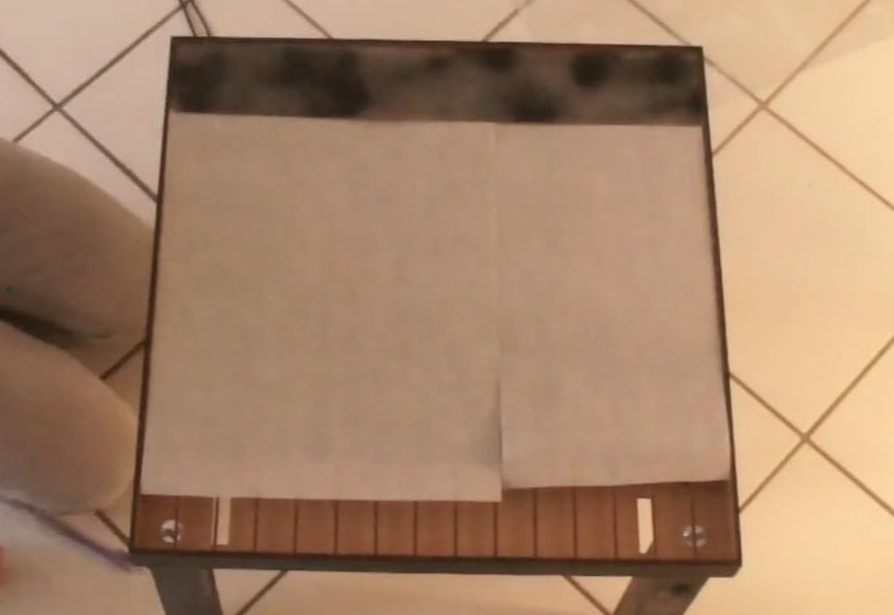
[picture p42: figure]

# Extension: touch keys

This step is not required but is an extension if you would like your table to be touch-sensitive. Although they are different and may return different types of output, touch feature can be provided by many kinds of sensors, including infra-red, barycentre of weight, vibration sensing, ... The method proposed here involves capacitive sensor connected to pieces of ITO plastic.

## Hardware

This plastic is covered with a thin conductive layer that makes it discrete underneath your glass as well as sensitive to capacitive changes. Only 1 side if generally conductive, identify which one thanks to an ohmmeter. Cut 6 pieces of ITO plastic slightly smaller than the size of two pixels i.e. 30x63mm.

The MPR121 sensor can have up to 12 keys. Connect its capacitive inputs 0 to 5 to wires going through Arbalet's pixels from the bottom of the table.

## Software activation of touch

By default the online SDK has touch features disabled. You can activate them by adding parameter -c config150touch.json when executing an app. Use the file default.cfg and reinstall the SDK to make this change permanent. This parameter loads a config file enabling 6 touch keys. For each app, activated touch keys will backlight in light white switching to strong white when they are pressed.

TODO: Better documentation, CAD drawing and pictures here

# Hack and share!

Recall that Arbalet is a hackable device, try and play the existing applications in the arbapps repository.

(https://twitter.com/arbalet_project)Do not hesitate to share pictures of your build status with us, keep in touch and tell us your news on twitter:

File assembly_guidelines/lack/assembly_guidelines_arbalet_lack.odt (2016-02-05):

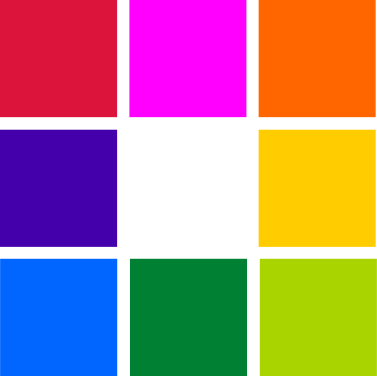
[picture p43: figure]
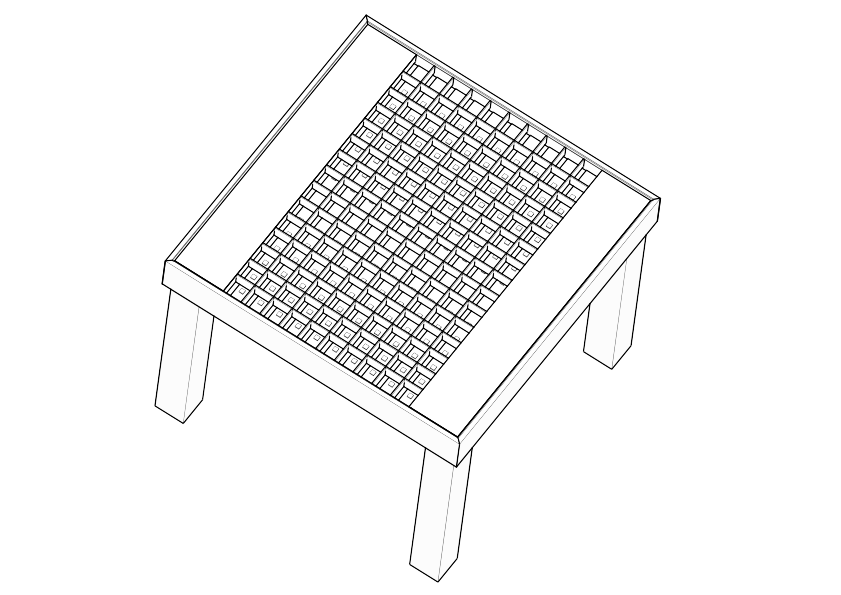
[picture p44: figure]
3DVIA Composer Export

Assembly guidelines for DIY building

Arbalet LED table

Lack variant

Preliminary notes

This document describes how to build an Arbalet LED table licensed under an Open Hardware CC-BY-SA licence (https://creativecommons.org/licenses/by-sa/3.0/). It is then permitted and formally encouraged to take inspiration from this work to build new Open Hardware items and publish them to the community.

Last edit: 5 February 2016

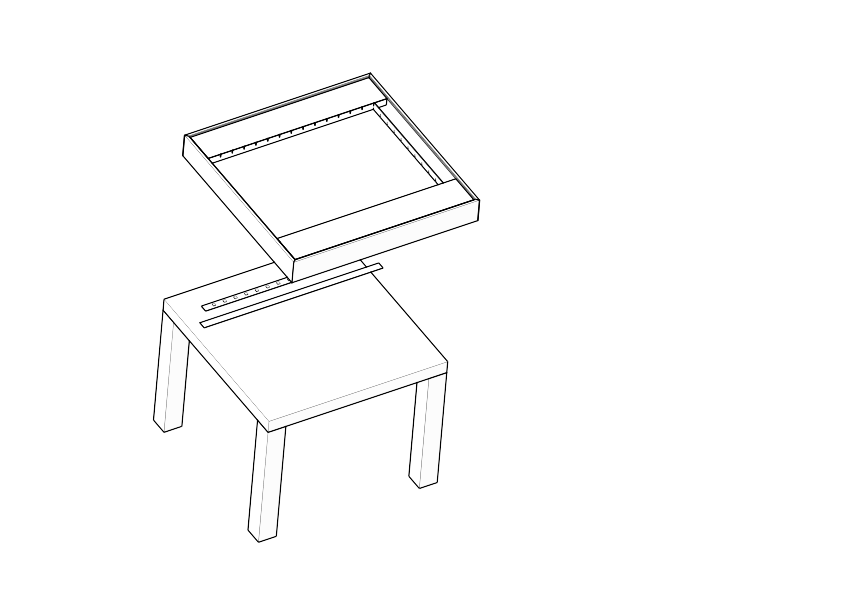
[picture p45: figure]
3DVIA Composer Export

1. Overview of the overall assembly Illustration 1: Exploded view of the table: the table tray and the additional tray

The LED table is built with an Ikea Lack table. 10 LED strips are stuck over the table tray thanks to adhesive tape. An additional tray delimits the pixels and will support the weight of objects.

Illustration 1 shows the additional tray as a single block, the detail is shown on the next illustration.

Illustration 2 shows a complete exploded view, each layer being:

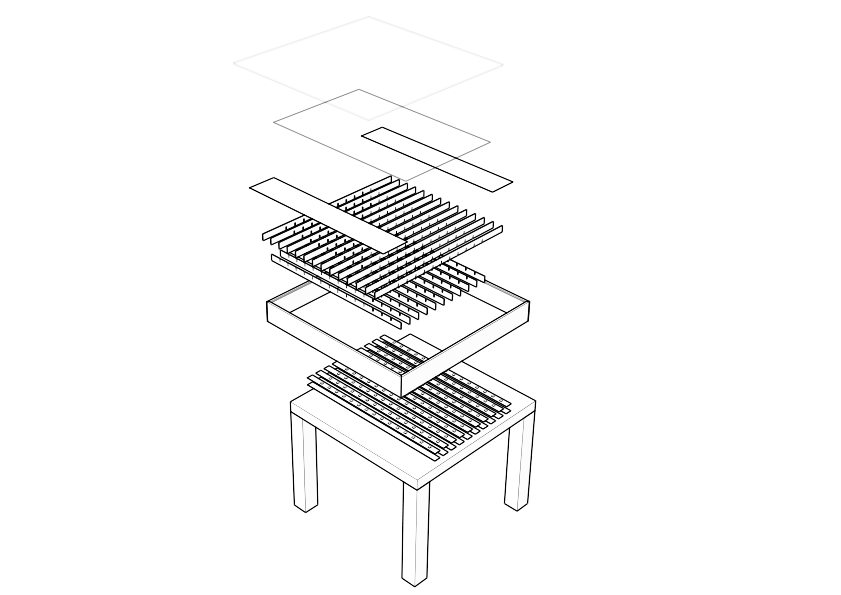
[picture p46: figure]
3DVIA Composer Export

Illustration 2: Full exploded view of the table

- The original Ikea table
- The LED strips stick onto the table thanks to adhesive tape
- The outer frame
- The inner grid
- 2 pieces of opaque paper hiding the unpixelated surface
- The diffuser: A piece of cooking paper
- The glass
2. Bill of materials (BOM)
- An Ikea “Lack” table

Arbalet Lack variant uses an Ikea coffee table model “Lack” dimensions 500x500 mm.

Warning: In some countries, newer versions of Ikea Lack side tables have dimensions 550x550, these guidelines assume that you are hacking a 500x500 table.

- A LED strip

A 5m LED strip with WS2812B chips of density 30 LEDs per meter. The density defines what size the final pixels will be, in this case 33.3x33.3 mm. The strip is presented as a 3 wire bus: Power + (red, aka 5V), Power – (black, aka GND for Ground) and Data (green, or any other color). The Data line is ordered, in the sense that each chip has a Data IN (DIN) and a Data OUT (DOUT), so we must always connect a Data IN to a Data OUT.

- An Arduino Leonardo microcontroller

The Arduino microcontroller will receive the pixel matrix from Python and generate the data signal to the LED strip. You can also use an Arduino Uno or any other Arduino board. Don't forget its micro USB cable (or mini USB depending on your version).

- A 5V power supply >5A

Use a regulated power supply of at least 5 amps.

- Some wires ~ 20 AWG

The wires will be used to connect the cut sections of the LED strip. We will need to connect 3 wires: Power + (red), Power - (black) and Data (green, or any other color). The 2 power wires will drive up to 5A and might melt if they are too thin. The strip is sold with a 20 AWG cable, meaning that its copper inner wire is 0.8 mm thick. You should keep this section for the 2 power wires for safety purposes. For the Data line, you might use a very thin wire as it drives very few current. If you want to calculate precisely the section of power wires, refer to the standard (https://en.wikipedia.org/wiki/American_wire_gauge).

- A credit card sized soldering board

This card will go right above the Arduino, fastened to the microcontroller thanks to pin headers. You can also use soldering boards dedicated to Arduino, already mounted with PIN headers and screw connectors if you're not familiar with soldering.

- Some male pin header (optional)

Only few pins will actually be used, but using more pins will fasten the board stronger to the Arduino.

- A DC power barrel jack (optional)

Have a deeper look to the power supply you have selected and its type of plug. Order the soldering-compatible female socket that will allow to plug the power supply.

- A 100 to 200 µF capacitor (optional)

If your power supply is shoddy, this capacitor can help it to provide enough energy to the LED strip in case of peaks of current, for instance when all pixels are suddenly lit from black to full brightness.

- A 220 Ω resistor (optional)

A resistor will help to decrease noise on the data line.

- 700x500 mm of 2 mm thick wood or plastic

This piece of wood will be used to build the grid separating the pixels from each other. Choose a material that is easy to saw.

- 260x525 mm of 10 mm thick wood

This piece of wood will be the outer frame. This frame makes a ring to the table and has to be screwed to the table tray in order not to fall down. A groove made at the top will host the glass and prevent it of slipping.

- 500x500 mm of 4 mm thick glass

The glass will finish the surface. Using toughened glass is better for safety purposes in case of breaking, however its tough properties make cutting difficult or impossible. Ask advises to your local mirror dealer. You should NOT cut it before having built the wooden frame to ensure that it will properly fit the frame.

- Other material and tools

Cooking paper or privacy sticky film to diffuse the light, some black paper with 500 mm length to be used as a cover outside at the place there is no pixel, black paint for the outer frame, > 8 wood screws to fasten the frame to the tray, double-sided tape, a soldering iron and tin, a saw or any machine to help you cutting the wood/plastic, a cutter, a long ruler, a pencil and scissors. Also do not forget that you will need a laptop connected to the Arduino since Arbalet is Python powered; alternatively you might use a raspberry pi computer or any computer able to run a Python interpreter.

3. Prepare the LED strip

# Remove the rubber sheath

If your strip comes with a waterproof silicone rubber sheath, remove it carefully using a cutter. Be careful not to damage the LED strip itself. The 2 endpoints of the strip are drown into rubber and require special attention.

You can throw away the cut rubber sheath that is not used in this project.

# Cut the LED strip into 10 pieces of 500 mm each (15 LEDs each)

Use scissors and make sure you keep a soldering area to resolder both sides of the string after cutting.

You have now 10 pieces of strips, two of them have factory-soldered connectors.

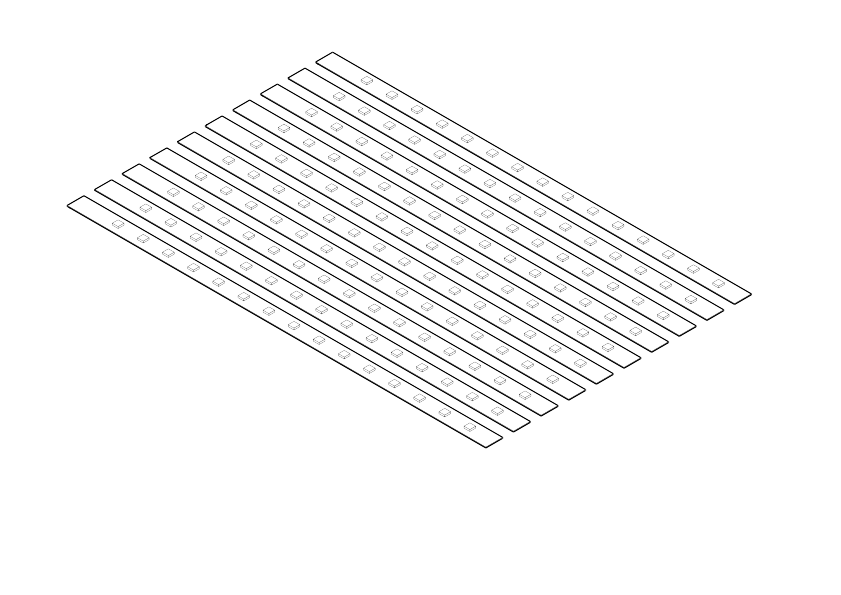
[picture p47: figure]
3DVIA Composer Export

Illustration 3: 10 cut pieces of strips with 15 LEDs each

# Unsolder the factory-soldered female connector

The LED strip comes with a male and a female connectors. Unsolder the one that is connected to a DOUT pin and keep it on hand we will reuse it for the connection Arduino ↔ LED strip. Make sure you don't overheat the strip while unsoldering. Do not unsolder the cable that is connected to the DIN side.

You have now 10 pieces of strips, and only one of them has a factory-soldered male connector.

4. Prepare the table

# Draw 10 centred lines separated by 33.3 mm each with a pencil

These lines will help you to stick the 10 strips over the table. Make sure they are centred and separated by 33.3 mm from each other. Centring them will leave 2 empty spaces of 100 mm of both sides.

# Arrange the strip over the tray and stick them with double-sided tape

WARNING: Recall that the Data line is ordered. Alternate DIN and DOUT pins to form a coil. The coil is a succession of DIN to DOUT connections. Some strips have arrows printed to highlight the direction of the Data line.

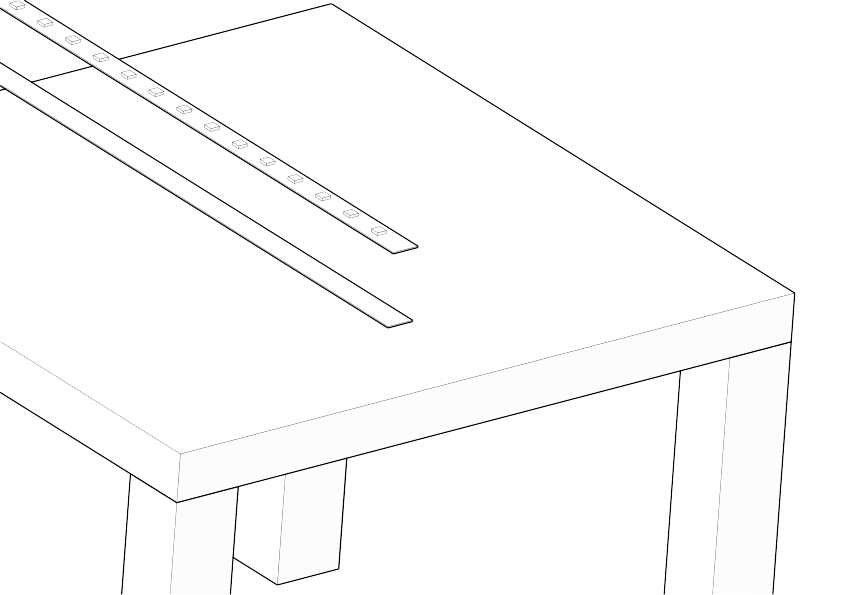
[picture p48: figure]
3DVIA Composer Export

Illustration 4: Sticking of the portions of LED strips over the table using double-sided tape

5. Prepare wires

# Cut 3x9 50 mm long wires

They will fix the connection we have destroyed by cutting the strip into pieces to form a new chain of LEDs. If you have 3 different colours of wires, use them to distinguish Power +, Power - and Data. Make sure they are long enough to create arcs of a circles between each strip.

Do NOT touch the female connector unsoldered at step 3C, we will use this one later.

# Solder the wires to reform the strip

Connect all 5V (red) together, all GND (black) together, and all DATA (often green or yellow) together. Check another time that you always connect DIN to the next DOUT. Never connect ~~DIN to DIN~~ nor ~~DOUT to DOUT~~. In case of mistake, you will need to unstick the strips not correctly arranged during step 4B.

6. Circuit board

Before going further we make a break and test that that we did not break the LED strip. To do so we need the circuit board, whose diagram follows.

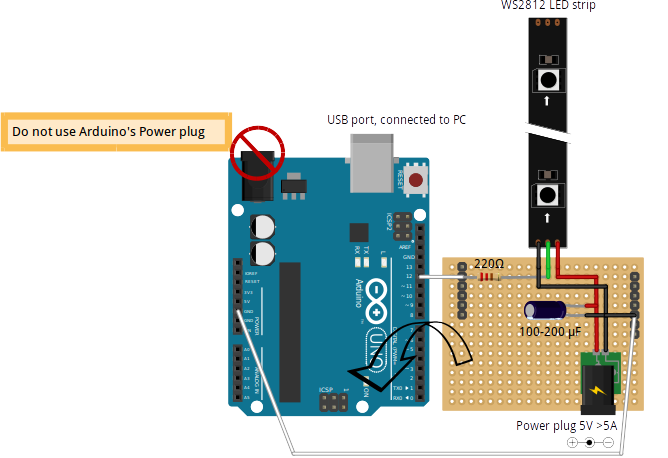
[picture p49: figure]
layer 21

Illustration 5: Circuit board

The custom board will be mounted right above the Arduino board, with its male PIN headers directly plugged in Arduino's female headers, ensuring its fastening as well as its data connection.

White wires on the diagram below are not actual wires but direct male-female connections of PIN headers.

Components will be wedged between both boards, so make sure that there are not too big to avoid the boards being plugged together. The capacitor and the DC power plug are the big components that could prevent connection of boards.

Then follow the Hardware and Software preliminaries (https://github.com/arbalet-project/arbadoc/wiki/Hardware-and-Software-preliminaries) until Arbalet firmware is uploaded before continuing. If something went wrong during soldering you will figure it out during these tests before it becomes less easy to fix the hardware problems.

Fix your electronics under the table thanks to double-sided tape or tiny screws and jump to step 7 only after having successfully run at least the color demonstrator on your new hardware using the -w flag to enable hardware. Ensure that all pixels are driven and able to light. If you meet troubles, find help in the troubleshooting (https://github.com/arbalet-project/arbadoc/wiki/Troubleshooting) section.

7. Make the grid

The inner grid separate each pixel from each other and must be strong enough to support the glass and the weight applied to its surface. The assembled grid is shown on illustration 6.

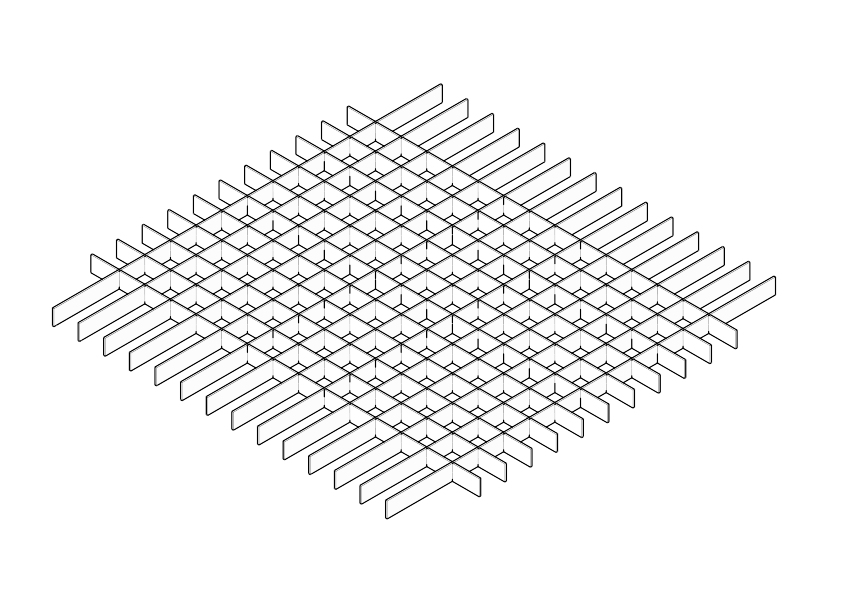
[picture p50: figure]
3DVIA Composer Export

Illustration 6: Assembled inner grid

# Cut 35 identical strips of 500 x 20 mm in the 2mm-thick wood or plastic

# Create 14 10mm-long grooves regularly spaced

Make the grooves really slack, since addition of imprecisions will make the final crossing of the 35 strips very tight. To improve precision you should stack the 35 strips and pierce them all at once. If you want to make things cleanly only 11 strips requires 14 grooves, the 14 other strips only need 11 holes, but by piercing identically the 35 strips, the extra grooves will be hidden by a cover and not visible.

# Insert them one inside the other

The more pieces you insert, the more stretched the construction will be. You might need to force a little bit to insert the last pieces. Start by inserting the outer sides and go inward.

The 11 hole pieces must be all perpendicular to the 14 hole pieces, as shown on illustrations 7 and 8. If you pierced all the 35 pieces with 14 holes, some holes will stay unused so make sure you make a symmetric construction.

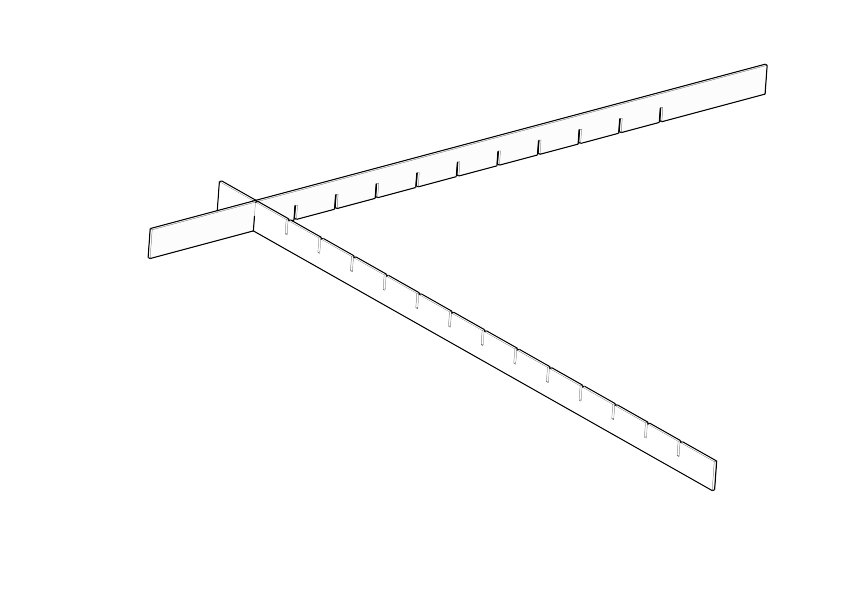
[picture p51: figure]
3DVIA Composer Export

Illustration 7: Insertion of the strips of the inner grid

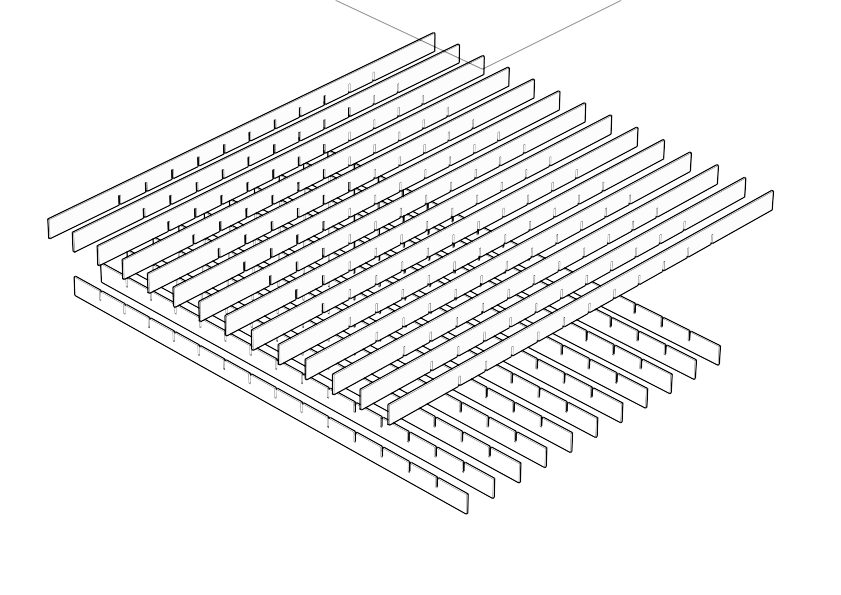
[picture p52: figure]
3DVIA Composer Export

Illustration 8: Full disposition of the strips of the inner grid

8. Make the outer frame

# Cut 4 identical pieces of wood with a groove hosting the glass

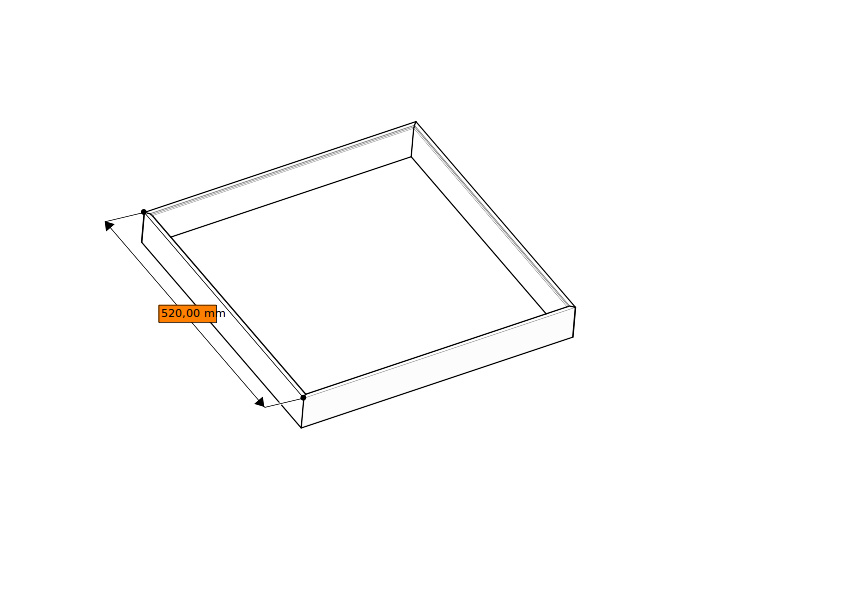
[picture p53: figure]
3DVIA Composer Export

Illustration 9: Wooden outer frame hosting the glass

The groove is located to the inner top of the frame and should be large enough to host the glass. Make sure it is slack enough to host the glass without forcing but large enough to support the load.

# Make a frame by fastening the pieces with very thin nails

Check first that the dimensions of your frame are large enough to largely fit around the table tray, as a ring.

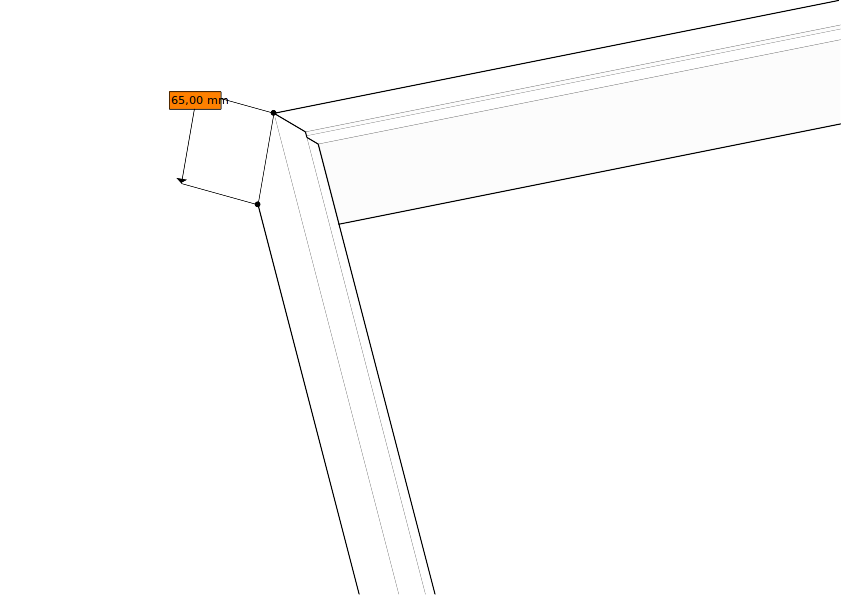
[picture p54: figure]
3DVIA Composer Export

Illustration 10: Zoom on the outer frame

# Cut out pieces of cooking paper to cover the pixelated area of 500x333 mm

The paper will be trapped between the grid and the glass. It must cover only the rectangular surface filled with pixels.

# Cut out two pieces of black paper to hide the grid where there is no pixel.

# Check the final dimensions available to host the glass and cut a glass according to the available space

Theoretically the frame can host a 500x500 mm glass. In practice it will depend of the precision you managed to reach during the assembly of the frame. To absorb this lack of precision measure the a actual space available for the glass and cut a piece of glass that is at least 2 mm wide less than what is available. It is a good idea to bring your frame to your mirror retailer if you are not confident into your dimensions.

The glass put down on the frame must be slightly higher than the frame itself to avoid objects gripping the wood when you slip them along the table.

9. Enjoy, and share to the community

Take pictures of the result and post them on twitter mentioning @arbalet_project (https://twitter.com/arbalet_project) we'll be delighted to reweet and share your work!

If you have made customizations you might also create a howto similarly to this one.

Arbalet LED table – Lack variant – Licensed under CC-BY-SA 15/15

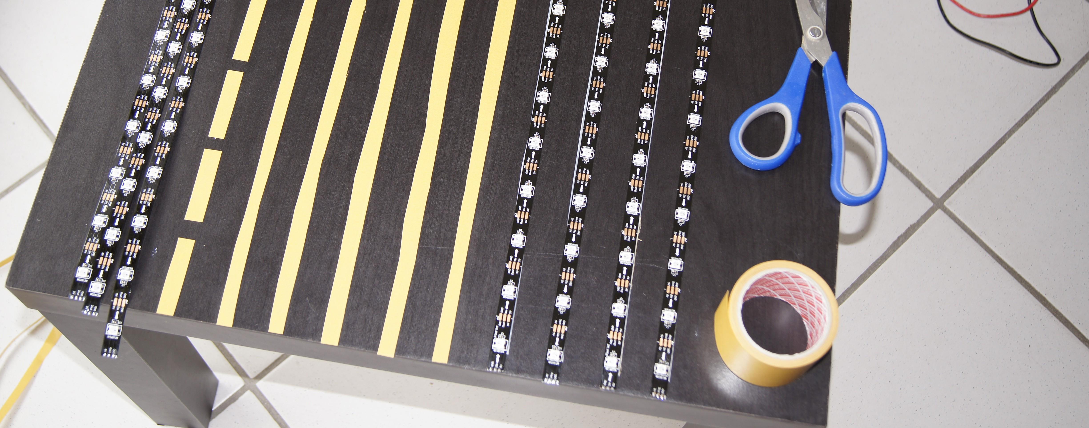
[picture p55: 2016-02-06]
pics/build_2.jpeg

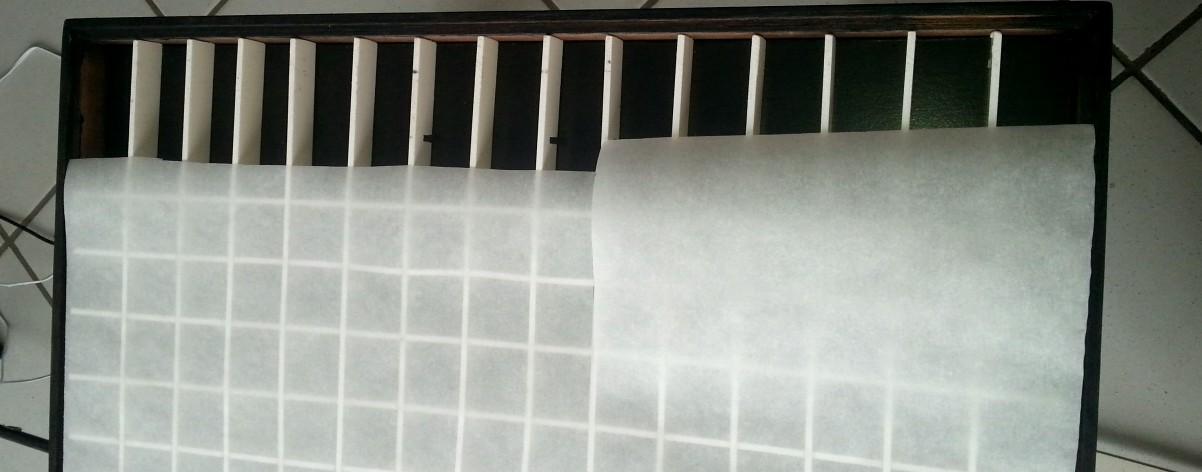
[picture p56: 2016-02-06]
pics/build_5.jpeg

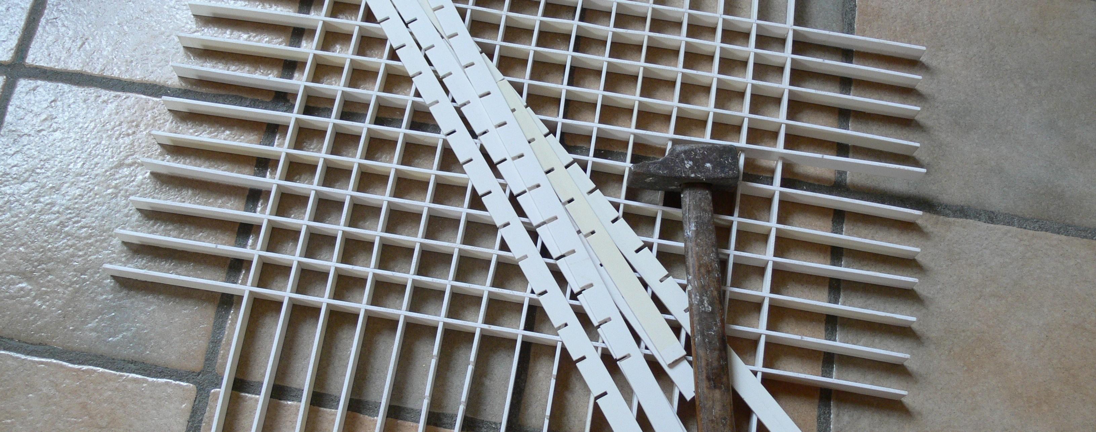
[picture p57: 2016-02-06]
pics/build_4.jpeg

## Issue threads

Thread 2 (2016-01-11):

missing electronic diagram

benoit-girard, 2016-01-11:
the assembly_guidelines_arbalet_lack.pdf, page 8 (5C) refers to an electronic diagram that does not appear in the document.

ymollard, 2016-01-12:
I must draw the circuit thanks to @fritzing ([Open source hardware program](http://fritzing.org)) but I'm really out of time at the moment, I have this [super fast draft](https://framapic.org/3RvLOqY8uyty/SCpS0hjv) on hand (The capacitor 20μF to 200μF or more, the resistor can be 100 Ω to 500 Ω).

I also accept PR for the Fritzing sketch ;)

ymollard, 2016-01-31:
The Fritzing diagram is now available in step 6 of the [assembly guidelines](https://github.com/arbalet-project/arbadoc/blob/master/assembly_guidelines/lack/assembly_guidelines_arbalet_lack.pdf).

Closed 2016-01-31.

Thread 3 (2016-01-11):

More precise specifications needed

benoit-girard, 2016-01-11:
If we do not want to order from pololu, more precise information about the requirements of the electronic parts are needed (specifications of the adapter, of the headers, etc.)

About the adapter: you recommend a 3A adapter on pololu, while your doc says that 5A are needed...

Et pour les utilisateurs français, qui ne voient pas trop l'intérêt d'acheter le matériel auprès d'un revendeur américain (beaucoup de transport pour rien), une traduction des noms de ces éléments permettrait de les trouver plus facilement sur les site web des revendeurs français...

ymollard, 2016-01-11:
I tried to detail more, let me know what you think and what information is still missing
3A was a typo, minimum is 5A per 150 LEDs.
I've also added the French translation to buy supplies at Leroy Merlin :) Most components can be found locally but for the strip It is waaaay cheaper to buy directly to Asian manufacturers however, so I advise ebay.

benoit-girard, 2016-01-12:
Note that in the English description of the adapter, you provide a link to a 3A adapter on pololu. The risk is high that someone buys it following your recommendation and ends up with an underpowered system...

benoit-girard, 2016-01-12:
OK, apparently, you changed that.

Closed 2016-01-12.

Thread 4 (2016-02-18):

Pb with Led test upload

benoit-girard, 2016-02-18:
I am in the "Hardware-and-Software-preliminaries", section "Install and test the Led strip library", and at step 4, the upload is unsuccessful...

Using a Mac, I have put the pololu library in Documents/Arduino/libraries, and I have access to the examples in the Arduino UI.

When trying to upload, I had the following error messages, which do not help much:

Bibliothèque non valide trouvée dans /Users/girard/Documents/Arduino/libraries/pololu-led-strip-arduino : /Users/girard/Documents/Arduino/libraries/pololu-led-strip-arduino
Bibliothèque non valide trouvée dans /Users/girard/Documents/Arduino/libraries/pololu-led-strip-arduino : /Users/girard/Documents/Arduino/libraries/pololu-led-strip-arduino

benoit-girard, 2016-02-18:
Ok, false alarm, lack of cleaning on my side, you can close the issue.

Closed 2016-02-18.

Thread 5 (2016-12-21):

Wrong power supply dimension

LemarinelNet, 2016-12-21:
Hi,

I've made a small calculation :
Each WS2812B module contains 3 LED, and each led can consume up to 20 mA.
This leads to 60mA per LED.
So, for a table containing 150 LED, if each led is set at full power white, we need 150 x 0.06A = 9 A !

I think that asking for a 5V / 5A power supply could cause to strange behavior ;)

It should be more reasonable to ask for a 10 A PSU.

PS : Boujou de normandie !

AurelienC, 2016-12-21:
Hello,

Good remark.

I don't have find much documentation, but I find 50mA at 5V for the full brightness of R, G and B LEDs.
This is about 7.5 A for 150 LEDs.

Indeed, a very powerful PSU must be a good thing, but not necessary with a "normal" use of the table. A good 5A power supply can provide most power in a short period of time and each LED has a tank capacitor.

LemarinelNet, 2016-12-21:
Yes, that's right, for normal use, and if we don't use as a giant torch, 5A is certainly enough :)
Perhaps we should warn in the doc that 5A is sufficient for normal use, but at full power it will not be enough...

Also, what about a french documentation ?

ymollard, 2016-12-21:
It probably depends on the LED strips. I've made some measurements on my strips from different manufacturers, powered with a lab power supply, I actually never needed more than 3.5A even at full brightness. I have the feeling that the theoretical 50mA per LED is a bit overkill especially when multiplied by 150. Strong power supplies are bigger, this is maybe not something you want close to your coffee table.

>  Also, what about a french documentation ?

I do accept pull requests on that repository :)

LemarinelNet, 2016-12-21:
I can't remember where I did saw those 20mA per LED, but nothing in the datasheet about IF current !!

It might be a general rule about led : when I did my high school, we did always took 20mA for a LED current... nevermind....

If I had some free time, I would translate the pages... perhaps someday ;)

LemarinelNet, 2016-12-21:
How should I proceed to translate the docs ? Should I suffix each file with "_fr". i.e. : assembly_guidelines_arbalet_lava_fr.odt ?
Or should I create a different subtree ?

ymollard, 2016-12-21:
If you follow the advice given by LED strips manufacturers they also suggest 7.5 amps or so.

Adding `_fr` is fine. You'll need the [`Oxygen`](https://fonts.google.com/specimen/Oxygen?selection.family=Oxygen) font.

LemarinelNet, 2016-12-21:
Great, I'll start translating the docs !
I'm not very used to Github.
Should I first fork the projects to be able to pull request after ?

ymollard, 2016-12-21:
Great! Yes, fork the project, then clone your own copy on your local disk (on Linux `git clone https://github.com/LemarinelNet/arbadoc.git`), then create the new file, then `git add the_new_file.odt`, then `git commit`, type a description of your work and save the result, you can do several commits and at the end `git push` to save your work online. The pull request is made afterwards from github.

LemarinelNet, 2016-12-21:
Ok ! I'll work on it as soon I'll have some free time :)

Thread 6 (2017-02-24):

Error in simulator - nothing is drawn within the simulator window

max2play, 2017-02-24:
Hi,

I set up everything according to your docs. Using a virtual machine with Debian Wheezy and Gnome.

This is the error message:
`user@develop: ~/Arbalet/arbapps$ python -m arbalet.apps.colors
Exception in thread Thread-2:
Traceback (most recent call last):
  File "/usr/lib/python2.7/threading.py", line 552, in __bootstrap_inner
    self.run()
  File "/usr/local/lib/python2.7/dist-packages/arbalet_core-3.0.0-py2.7.egg/arbalet/core/arbasim.py", line 64, in run
    self.display.fill(color.Color(pixel[0], pixel[1], pixel[2]),
ValueError: invalid color argument
`

The simulator window opens and if I remove the line that produces the error at least the vertical and horizontal lines are drawn. But nothing else happend - tried other demos as well.

Any ideas?

Thanks,
Stefan

max2play, 2017-02-24:
Found that the value of "pixel" is not useable by the Color function of PyGame. Forcing conversion to integer for the Pixel values solves the problem in /usr/local/lib/python2.7/dist-packages/arbalet_core-3.0.0-py2.7.egg/arbalet/core/arbasim.py:

`self.display.fill(color.Color(int(pixel[0]), int(pixel[1]), int(pixel[2])),
                                         Rect(w*self.cell_width,
                                         h*self.cell_height,
                                         self.cell_width,
                                         self.cell_height))
`

Maybe anyone else discovers the same problem - anyway NICE PROJECT!

Hope I could help you with my finding.

Stefan

ymollard, 2017-02-24:
They are normally numpy ints, funny your pygame does not accept them.
Could you give the output of `python -c "import pygame; print(pygame.__version__)"`?

Anyway a safe cast is worthy, would you mind commiting your changes and opening a pull request directly  on the master branch?

max2play, 2017-02-25:
PyGame version is "1.9.1release". Although the numbers of the pixel array look like ints, without the converions it does not work - I will create a pull request for the cast to integer.

ymollard, 2017-02-25:
I'm testing on 1.9.1release as well, it's strange.
Anyway thanks for the bug report and patch!

Closed 2017-02-25.

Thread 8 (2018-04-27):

Version 1 Laser Cutting

hakanatas, 2018-04-27:
Hi,
I am trying to make version 1. Is there any laser cutting file for it? (For inner grid)

ymollard, 2018-04-27:
Unfortunately no, because v1 is meant to be purely hand-made, so we have no file for laser cutting.
However, you can edit the grid from v2 to match the needs of v1 with [inkscape](https://inkscape.org/en/):
https://github.com/arbalet-project/arbadoc/blob/master/assembly_guidelines/lava/cad/svg/boards/3mm.svg
I advise you to keep 30mm tall pixels as in v2 because it diffuses light better, and if your wooden board is 3mm thick like files for v2 then you only have to check (and change?) the edges of the grid.

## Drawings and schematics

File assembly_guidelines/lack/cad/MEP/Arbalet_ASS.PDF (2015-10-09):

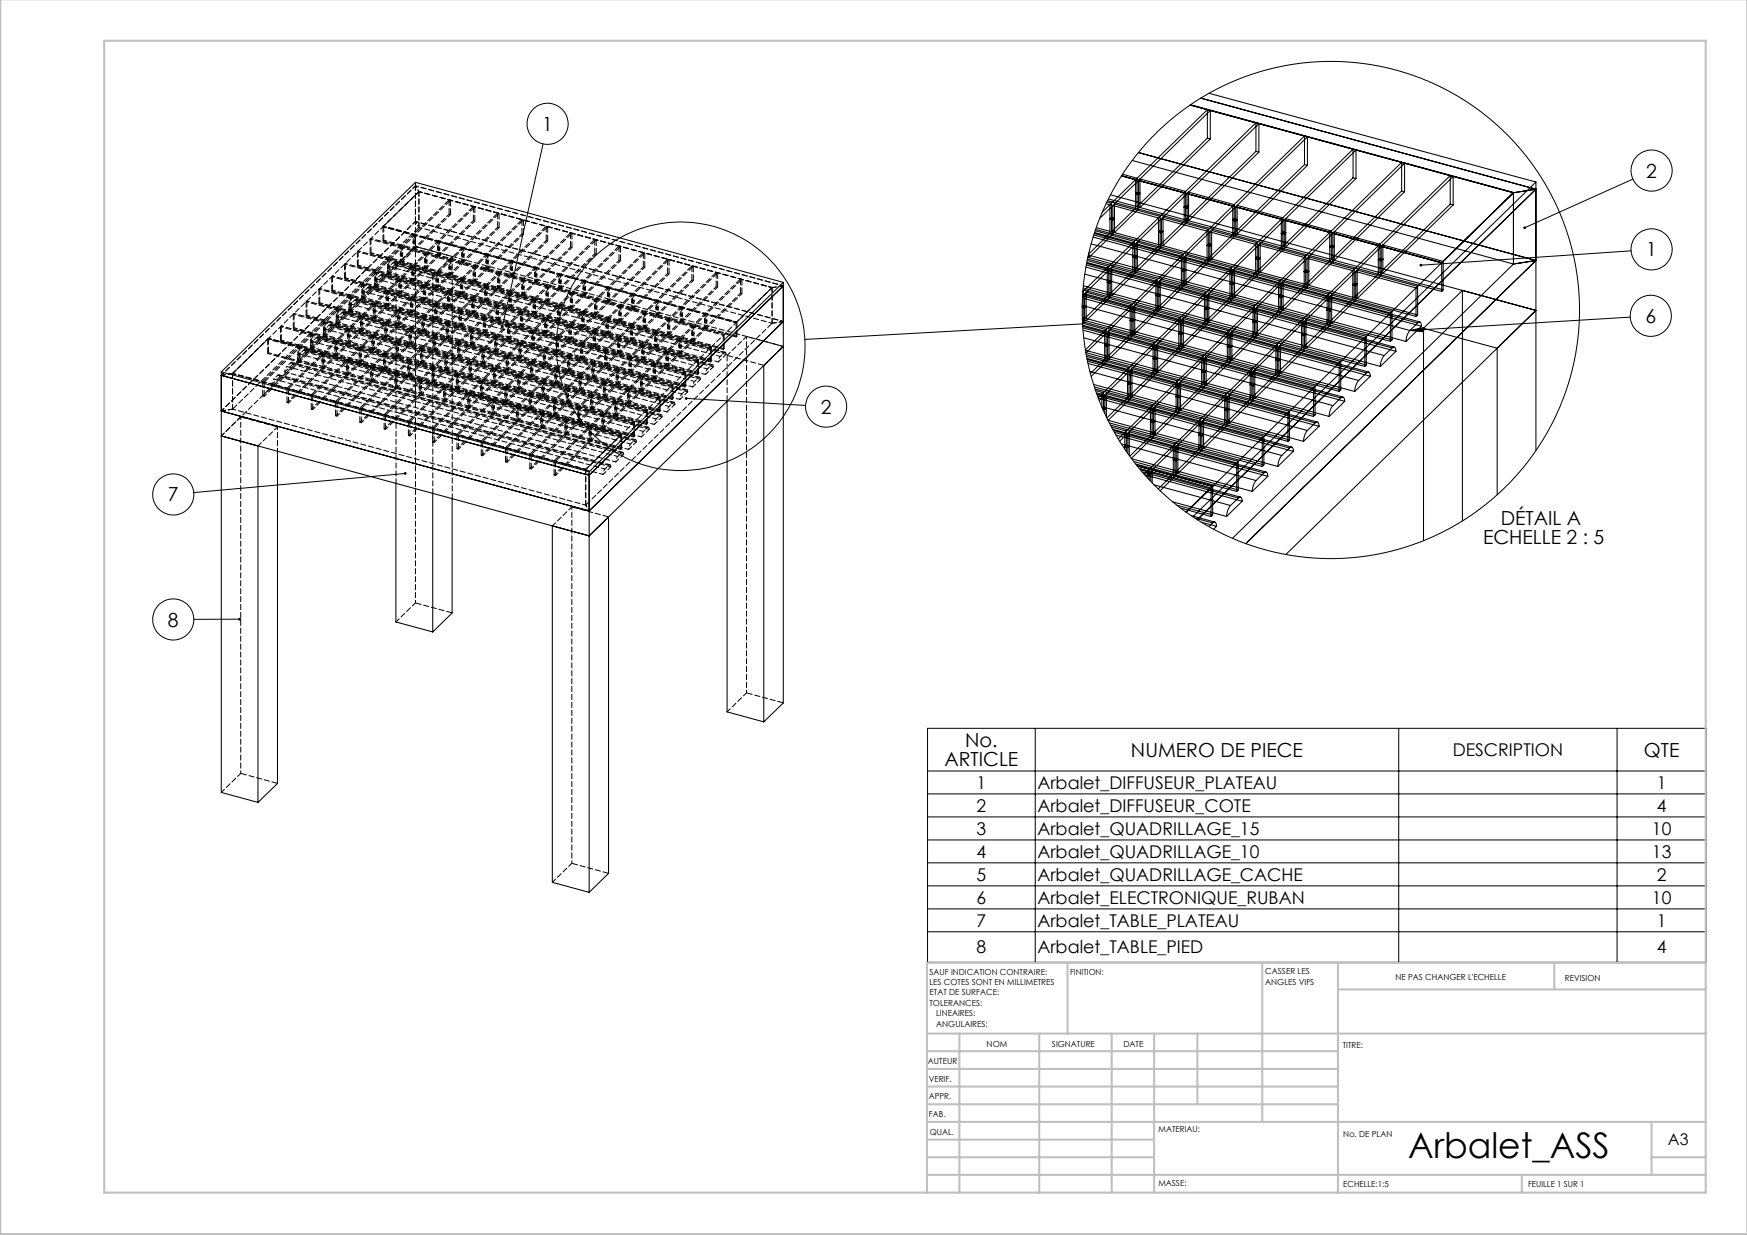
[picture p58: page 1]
DÉTAIL A ECHELLE 2 : 5; ECHELLE:1:5; FEUILLE 1 SUR 1

No. ARTICLE | NUMERO DE PIECE | DESCRIPTION | QTE
1 | Arbalet_DIFFUSEUR_PLATEAU | | 1
2 | Arbalet_DIFFUSEUR_COTE | | 4
3 | Arbalet_QUADRILLAGE_15 | | 10
4 | Arbalet_QUADRILLAGE_10 | | 13
5 | Arbalet_QUADRILLAGE_CACHE | | 2
6 | Arbalet_ELECTRONIQUE_RUBAN | | 10
7 | Arbalet_TABLE_PLATEAU | | 1
8 | Arbalet_TABLE_PIED | | 4

SAUF INDICATION CONTRAIRE: LES COTES SONT EN MILLIMETRES ETAT DE SURFACE: TOLERANCES: LINEAIRES: ANGULAIRES: | FINITION: | CASSER LES ANGLES VIFS | NE PAS CHANGER L'ECHELLE | REVISION

NOM | SIGNATURE | DATE | | | | TITRE:
QUAL. | | | | MATERIAU: | Arbalet_ASS MASSE: No. DE PLAN | A3

AUTEUR
VERIF.
APPR.
FAB.

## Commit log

2015-07-14 Prepared the ground for the assembly guide
2015-08-01 Added the assembly guidelines without CAD
2015-10-09 Add CAD files
    [Arbalet_ASM.SLDASM, Arbalet_ASM_step.STEP, Arbalet_ASS.SLDDRW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]
2015-10-24 Integrated the svg in the assembly guidelines (beta version)
2015-10-31 Updated CAD files and STEP file and Adding SVG
    [Arbalet_ASM.SLDASM, Arbalet_ASM.STEP, Arbalet_GRID_ASM.SLDASM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]
2015-11-01 Added the last SVGs to the assembly guidelines
2016-01-31 Issue #2 Added the Fritzing diagram and updated assembly guidelines
    [wiring.fzz]
2016-02-26 Uploaded unassembled parts of Arbalet Lava
    [bottom.fcstd, glass.fcstd, side_333.fcstd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]
2016-02-26 Bugfix: bottom: wrong array shift
    [bottom.fcstd]
2016-02-26 Bugfix: Side 333: wrong reference to vertical array hole
    [side_333.fcstd]
2016-02-26 Bugfix: Side 500: Deleted extra hook
    [side_500.fcstd]
2016-02-26 Added grid assemblies
    [grid.fcstd, strips_333.fcstd, strips_500.fcstd]
2016-02-26 Added host box assembly
    [host_box.fcstd]
2016-02-26 Added legs and assembly host + grid + legs
    [host_box_grid.fcstd, host_box_grid_legs.fcstd, leg.fcstd]
2016-02-26 Added comments about assemblies
2016-03-01 Restoring missing expressions of strips
    [strip_333.fcstd, strip_500.fcstd]
2016-03-01 Host MDF 5mm + Bugfix mission expression in side_500
    [bottom.fcstd, host_box.fcstd, host_box_grid.fcstd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]
2016-03-01 Smaller fingers (25mm)
    [bottom.fcstd, host_box.fcstd, host_box_grid.fcstd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]
2016-03-02 bottom part pierced for screws and cable passing
    [bottom.fcstd, host_box.fcstd, host_box_grid.fcstd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]
2016-03-02 side_500 with cable passing
    [grid.fcstd, host_box_grid.fcstd, host_box_grid_legs.fcstd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]
2016-03-07 Added unprocessed SVG 6mm/3mm
2016-03-11 Added boards
2016-03-13 + 5mm
2016-03-13 3mm/6mm + bugfix cable passings located at the opposite side
    [bottom.fcstd, grid.fcstd, host_box.fcstd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]
2016-04-19 Version 1 of Lava assembly guide
2016-04-23 Added wiring
    [wiring.fzz]
2016-04-23 Updated the tutorials after switching to protocol v2
2016-04-23 Alternated wire passings of side_500
    [grid.fcstd, host_box_grid.fcstd, host_box_grid_legs.fcstd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]
2016-04-23 Modified both extremities of strips_500 with no wire passing
    [grid.fcstd, host_box_grid.fcstd, host_box_grid_legs.fcstd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]
2016-04-24 CAD: Added the final assembly
    [cover_sheet.fcstd, covered_assembly.fcstd]
2016-04-29 guidelines: added strip assembly CAD
2016-04-29 guidelines: added LED placement CAD
2016-05-11 Documentation Lava: touch keys + BOM checklist + finishing stage
2016-10-20 Added 4 strip_500 with double cable passings for power supply
    [strip_500_double.fcstd]
